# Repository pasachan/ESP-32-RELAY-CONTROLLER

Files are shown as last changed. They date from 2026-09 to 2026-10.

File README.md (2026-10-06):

# ESP32 Relay Controller

**An 8-channel relay controller with Wi-Fi, an RS-485 field bus, and a 12 V power rail for downstream nodes.**
Designed as the master board for a small home-automation network: this board switches loads directly, talks to
the outside world over Wi-Fi, and powers and polls a chain of low-cost slave boards (ATtiny / STM32 class) over RS-485.

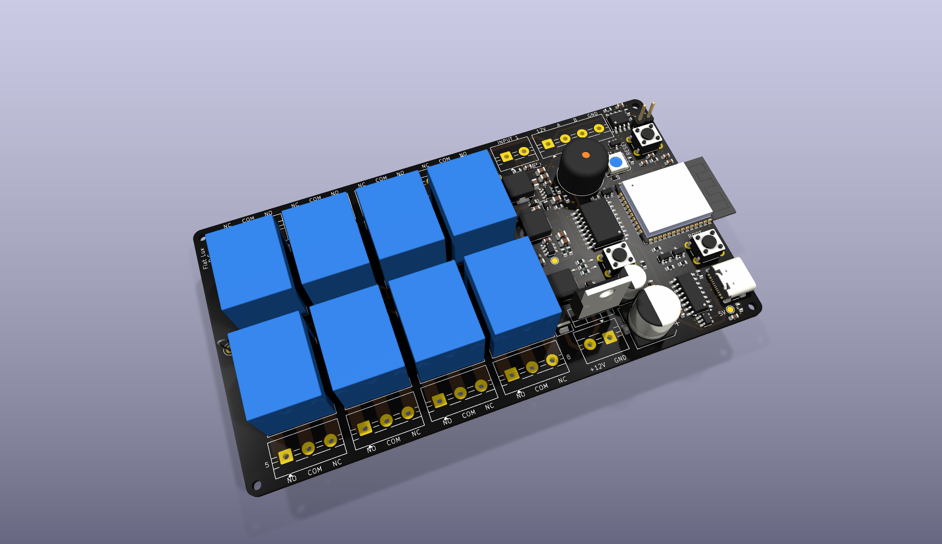
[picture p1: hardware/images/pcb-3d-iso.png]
Board render


Open hardware. KiCad 10 source, fabrication outputs, BOMs with LCSC part numbers, and a pick-and-place file are all in this repository. Rev 1 has been manufactured.

---

## Features

- **ESP32-WROOM-32D** (16 MB flash) — Wi-Fi + Bluetooth, USB-C programming via CH340C with auto-reset
- **8 × SPDT relays** (SRD-05VDC, 10 A contacts), driven by a ULN2803A with built-in flyback clamps, each brought out to a 3-way screw terminal (NO / COM / NC)
- **RS-485 half-duplex master** — MAX3485 (3.3 V), SM712 surge protection, jumper-selectable 120 Ω termination, fail-safe biasing
- **12 V field bus power** on the RS-485 connector, so slave nodes need no local supply
- **12 V input** with P-FET reverse-polarity protection, bidirectional TVS, and an LC input filter
- Two synchronous bucks (LMR51430): 5 V for relay coils, 3.3 V for logic — the 3.3 V rail also runs from USB alone for bench programming
- One dry-contact input (pull-up, RC filter, ESD clamp), active buzzer, WS2812B status LED, rail indicator LEDs
- RESET / BOOT / user (WPS) buttons, 2 mm mounting holes, 124.75 × 68 mm, 2-layer

---

## Block diagram

```mermaid
flowchart LR
    J1["12 V input"] --> Q1["IRF4905<br/>reverse-polarity FET"] --> L3["LC input filter"] --> V12["+12 V rail"]
    D2["SMBJ18CA TVS"] -.clamps.-> J1
    V12 --> U2["LMR51430<br/>buck → 5 V"] --> V5["+5 V coil rail"]
    V12 --> D3["Schottky OR"] --> U3["LMR51430<br/>buck → 3.3 V"] --> V33["+3.3 V logic"]
    USB["USB-C"] --> U4["USBLC6 ESD"] --> U6["CH340C"] <-->|"UART0 + auto-reset"| U1
    USB -->|"VBUS"| D4["Schottky OR"] --> U3
    V33 --> U1["ESP32-WROOM-32D"]
    U1 -->|"8 × GPIO"| U7["ULN2803A"] -->|"8 × coil"| K["K2 … K9<br/>SRD-05VDC SPDT"] --> JT["8 × NO/COM/NC<br/>screw terminals"]
    V5 --> K
    U1 <-->|"UART2 + DE/RE"| U9["MAX3485<br/>RS-485"] --> D6["SM712 TVS"] --> J12["Field bus<br/>12V · A · B · GND"]
    V12 --> J12
    U1 --> BZ["Buzzer"]
    U1 --> LED["WS2812B"]
    IN["Dry-contact input"] --> U1
```

---

## Specifications

| | |
|---|---|
| Supply | 12 V DC nominal (LMR51430 bucks accept 4–36 V; TVS clamps at 18 V standoff) |
| Board draw @ 12 V | ~170 mA idle · ~520 mA worst case (all relays + Wi-Fi TX) |
| Field-bus power budget | ~1.8 A at 12 V on J12 — set by the 1.0 mm feed trace (2.4 A @ 10 °C rise) less the board's own draw; L3 is rated 4.5 A |
| Relay contacts | SPDT, 10 A / 250 VAC rated · **PCB traces sized for ≤ 2.3 A at 12–30 V** (see [design notes](docs/design-notes.md#relay-bank-and-switched-load-clearances)) |
| Relay coil drive | ~4.0 V at the coil vs 3.75 V pick-up spec — all eight channels |
| RS-485 | Half-duplex, 3.3 V transceiver, 120 Ω termination via JP1, 330 Ω fail-safe bias (this node only) |
| USB | USB 2.0 Full Speed (CH340C), USB-C receptacle, 5.1 k CC pull-downs, VBUS ESD array |
| Logic level | 3.3 V throughout; WS2812B fed through a series diode so 3.3 V data meets its V<sub>IH</sub> |
| Dimensions | 124.75 × 68 mm, 1.6 mm FR-4, 2 layers, 1 oz copper |
| Mounting | 4 × Ø2.0 mm holes at the corners |

---

## Repository layout

```
esp32-relay-controller/
├── README.md
├── hardware/
│   ├── kicad/                     KiCad 10 project (schematic, PCB, custom rules, project symbol lib)
│   ├── fabrication/
│   │   ├── gerbers/               RS-274X gerbers + Excellon drill files (fab layers only)
│   │   ├── esp32-relay-controller-gerbers.zip
│   │   ├── BOM.csv                Master BOM — every fitted part, SMD and through-hole, with LCSC + MPN
│   │   ├── BOM-JLCPCB.csv         SMD-only, JLCPCB column format
│   │   ├── BOM-PCBWay.csv         SMD-only, MPN-first for PCBWay
│   │   ├── CPL.csv                SMD pick-and-place (Designator / Mid X / Mid Y / Layer / Rotation)
│   │   └── README.md              How to order
│   └── images/                    Renders and layer plots
├── docs/
│   ├── schematic.pdf
│   ├── design-notes.md            Design decisions, the review process, and what changed as a result
│   └── pinout.md                  ESP32 GPIO map, relay ↔ terminal ↔ GPIO table, connector pinouts
└── firmware/
    ├── README.md                  Pin definitions and the gotchas that bite firmware authors
    └── self-test/                 Bring-up sketch — exercises every component, no libraries needed
```

---

## Getting boards made

Everything a fab needs is in [`hardware/fabrication/`](hardware/fabrication/). The short version:

1. Upload `esp32-relay-controller-gerbers.zip` for the bare PCB — 2 layer, 1.6 mm, 1 oz, any colour.
2. For SMD assembly, upload `BOM-JLCPCB.csv` + `CPL.csv` (JLCPCB) or `BOM-PCBWay.csv` + `CPL.csv` (PCBWay). 72 SMD parts, 35 lines.
3. Hand-fit the 25 through-hole parts: 8 relays, 11 screw-terminal blocks, the TO-220 FET, buzzer, three tact switches and the termination header. All are common parts; LCSC numbers are in `BOM.csv`.

See [`hardware/fabrication/README.md`](hardware/fabrication/README.md) for gerber-origin caveats, the one DFM query a fab may raise, and which parts are safe to substitute.

---

## Firmware quick reference

[`firmware/self-test/`](firmware/self-test/) is a bring-up sketch that exercises every fitted component and prints a pass/fail report over USB serial. Run it first on a new board. Full map in [`docs/pinout.md`](docs/pinout.md), gotchas in [`firmware/README.md`](firmware/README.md).

| Function | GPIO | Notes |
|---|---|---|
| Relay 1 … 8 (silkscreen order) | 14, 19, 25, 13, 23, 33, 32, 18 | Active-high into ULN2803A |
| RS-485 TX / RX / DE+RE | 17 / 16 / 2 | GPIO2 has a 10 k pull-down → receive mode at boot |
| Dry-contact input | 34 | Input-only pin, external 10 k pull-up, closes to GND |
| User button (WPS) | 35 | Input-only, 10 k pull-down, pressed = high |
| Buzzer | 26 | Via NPN, active-high |
| WS2812B data | 27 | Through 330 Ω |
| UART0 (USB) | 1 / 3 | CH340C with DTR/RTS auto-reset |
| I²C | 21 / 22 | Routed to pads but **no pull-ups fitted** in rev 1 |

---

## Design notes

The interesting engineering is in [`docs/design-notes.md`](docs/design-notes.md). Highlights:

- **Why the field bus carries 12 V and not 3.3 V** — cable drop and the thermal ceiling of a SOT-23-6 buck make 3.3 V distribution a dead end past a couple of nodes; regulating at each slave costs one LDO and removes the constraint.
- **Reverse-polarity protection with a P-FET, and why the TVS sits in front of it** — a unidirectional clamp ahead of the FET would short a reversed supply, so it's a bidirectional part.
- **Relay coil drive margin** — the SRD-05VDC needs 3.75 V to pull in; behind a ULN2803A the coil sees ~4.0 V. A series diode in the original design put one channel *under* the limit and was removed.
- **Driving a 5 V WS2812B from a 3.3 V GPIO** — a diode in the LED's supply drops V<sub>DD</sub> into the window where 3.3 V is a valid high, without a level shifter.
- **A KiCad DRC gotcha** — custom rules that match on auto-generated net names like `Net-(J2-Pin_1)` silently never fire. The rules in this project match on a netclass instead.
- **What the design review caught** — the board went through a full netlist, DRC, ERC and geometric-connectivity audit before ordering; the findings and fixes are documented.

---

## Status

| Revision | Date | Notes |
|---|---|---|
| **Rev 1** | Sep 2026 | Ordered. 0 DRC errors, 0 unconnected nets, all nets verified single-island. |
| **Rev 1** | Oct 2026 | **Built and brought up.** All eight relays, the buzzer, the WS2812B, both inputs, the RS-485 receiver and the USB programming path work. One firmware-level finding: the MAX3485's RO pin is tri-stated during transmit and has no pull-up, so it needs one enabled in software — [details](firmware/self-test/README.md#finding-ro-floats-during-transmit). |

Known rev 1 limitations and the planned rev 2 changes are listed at the end of the [design notes](docs/design-notes.md#rev-2-backlog).

---

## Licence

Copyright © 2026 Pareekshit Sachan.

This source describes Open Hardware and is licensed under the **CERN-OHL-P v2** (`SPDX-License-Identifier: CERN-OHL-P-2.0`). You may redistribute and modify this documentation and make products using it under the terms of the CERN-OHL-P v2 — see [`LICENSE`](LICENSE) or <https://cern.ch/cern-ohl>.

This documentation is distributed WITHOUT ANY EXPRESS OR IMPLIED WARRANTY, INCLUDING OF MERCHANTABILITY, SATISFACTORY QUALITY AND FITNESS FOR A PARTICULAR PURPOSE. Please see the CERN-OHL-P v2 for applicable conditions.

Symbols, footprints and 3D models from the KiCad libraries are used under the [KiCad library licence](https://www.kicad.org/libraries/license/) (CC-BY-SA 4.0 with exception). Datasheets referenced in the design notes remain the property of their manufacturers.

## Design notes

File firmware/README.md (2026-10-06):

# Firmware

[`self-test/`](self-test/) is a hardware bring-up sketch that exercises every fitted component and prints a pass/fail report over USB serial. It needs no libraries beyond the Arduino-ESP32 core. Run it first on a new board — it validates the relay silkscreen-to-GPIO mapping, which is not in an obvious order.

No application firmware is included yet. The rest of this file carries the hardware facts a firmware author needs on day one; the full table is in [`docs/pinout.md`](../docs/pinout.md).

## Pin definitions

```c
// Relays, in silkscreen order 1–8. Active-high into a ULN2803A.
static const uint8_t RELAY_GPIO[8] = { 14, 19, 25, 13, 23, 33, 32, 18 };

// RS-485 (MAX3485, half duplex) on UART2
#define RS485_TX_GPIO     17
#define RS485_RX_GPIO     16
#define RS485_DIR_GPIO     2   // high = transmit. External 10k pull-down → receive at boot.
                               // After Serial2.begin(), pull RS485_RX_GPIO up — see below.

// Inputs
#define INPUT1_GPIO       34   // dry contact to GND, external 10k pull-up, closed = LOW. Input-only pin.
#define USER_BUTTON_GPIO  35   // pressed = HIGH, external 10k pull-down. Input-only pin.

// Indicators
#define BUZZER_GPIO       26   // high = on
#define STATUS_LED_GPIO   27   // WS2812B data, single pixel

// I2C — routed to GPIO21/22 but no pull-ups fitted in rev 1
#define I2C_SDA_GPIO      21
#define I2C_SCL_GPIO      22
```

## Things worth knowing

- **Relays are off through reset and boot.** The ULN2803A inputs read low while the ESP32 pins are high-impedance. Initialise the relay GPIOs low before setting them as outputs to avoid a glitch.
- **GPIO2 (RS-485 direction) is a boot-strapping pin.** The external pull-down keeps it low at boot, which is what the ESP32 needs and also parks the transceiver in receive mode. Don't add an internal pull-up.
- **GPIO34 and GPIO35 are input-only** and have no internal pull resistors; the board provides external ones.
- **Turn-around on the RS-485 bus:** raise `RS485_DIR_GPIO` before writing, wait for the UART TX FIFO to drain (`uart_wait_tx_done`, or `Serial2.flush()` under Arduino), then drop it. Dropping it early truncates the last byte.
- **Pull the RS-485 RX pin up in software.** DE and RE̅ are tied together, so enabling the driver also disables the receiver — and a disabled MAX3485 drives RO to high impedance. Rev 1 fits no pull-up on RO, so GPIO16 floats for the whole of every transmission and the UART clocks in phantom bytes off the adjacent DI line. Measured on the first board: ~5 junk bytes per 18-byte frame at 9600 baud, with nothing attached to the bus. One line fixes it:

  ```c
  Serial2.begin(9600, SERIAL_8N1, RS485_RX_GPIO, RS485_TX_GPIO);
  gpio_set_pull_mode((gpio_num_t)RS485_RX_GPIO, GPIO_PULLUP_ONLY);  // must follow begin()
  ```

  That took the count to zero. A 10 kΩ pull-up on RO is in the rev 2 backlog.
- **The 5 V rail is absent on USB-only power**, so relays, the buzzer and the WS2812B do nothing while you're programming from a laptop. The 3.3 V logic rail works normally.
- **Module is the 16 MB flash variant** (ESP32-WROOM-32D-N16). Pick a matching partition table — `default_16MB.csv` under PlatformIO, or "16M Flash (3MB APP/9.9MB FATFS)" in the Arduino IDE.
- **Pick an upload rate that divides 6 MHz exactly** — 1500000, 1000000, 750000, 460800. **921600 and 576000 fail**, and not because they are too fast: 1500000 works and is 1.6× quicker. The CH340C's reachable rates are 6 000 000 / n on this host, so 921600 lands on 857143 instead, 7 % low, and the UART misframes. Details and the measured table are in [`self-test/README.md`](self-test/README.md#finding-the-ch340c-cannot-express-921600).

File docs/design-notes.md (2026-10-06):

# Design notes

Decisions, the reasoning behind them, and what a pre-fabrication review changed. Numbers quoted are measured from the KiCad files or taken from the referenced datasheets, not estimated.

Contents

- [Power input and protection](#power-input-and-protection)
- [Regulators](#regulators)
- [Relay bank and switched-load clearances](#relay-bank-and-switched-load-clearances)
- [Relay coil drive margin](#relay-coil-drive-margin)
- [RS-485 field bus](#rs-485-field-bus)
- [Why the bus carries 12 V, not 3.3 V](#why-the-bus-carries-12-v-not-33-v)
- [USB](#usb)
- [Status LED level shifting](#status-led-level-shifting)
- [Indicator LEDs](#indicator-leds)
- [Layout notes](#layout-notes)
- [Design-rule gotcha: net names with parentheses](#design-rule-gotcha-net-names-with-parentheses)
- [What the pre-order review caught](#what-the-pre-order-review-caught)
- [Rev 2 backlog](#rev-2-backlog)

---

## Power input and protection

```
J1 (+12 V) ──► D2 SMBJ18CA ──► Q1 IRF4905 ──► L3 10 µH ──► +12V_Protected ──► bucks, field bus
                (to GND)        P-FET             ▲
                                                  C1 470 µF · C2 100 µF · C12 10 µF
```

**Reverse-polarity protection is a P-channel MOSFET, not a diode.** Q1 (IRF4905, 20 mΩ) is wired drain-to-input, source-to-load, gate pulled to ground through 100 k with a 16 V zener (D5, BZX84-C16) clamping V<sub>GS</sub>. At the board's ~600 mA draw that is 12 mV of drop and 7 mW of loss; a Schottky in the same position would drop ~400 mV and burn 240 mW. With the input reversed the body diode is reverse-biased and V<sub>GS</sub> is zero, so nothing conducts.

The gate zener's orientation was worth checking against the part rather than the symbol: the BZX84 in SOT-23 is pin 1 = anode, pin 2 = no connection, pin 3 = cathode. The schematic uses KiCad's `Diode:BZX84Cxx` symbol, which has that pinout; a generic two-pin zener symbol on a three-pad footprint would put the anode on the NC pin and silently remove the clamp on the next schematic-to-PCB sync.

**The TVS sits ahead of the FET, and is bidirectional.** An earlier revision had a unidirectional SMAJ18A *after* the input inductor. A surge on the input then reached Q1's drain (rated −55 V) before anything clamped it, and L3's V = L·di/dt during the edge added tens of volts on top of the clamp voltage. Moving the clamp to the connector fixes that — but a *unidirectional* TVS ahead of the reverse-polarity FET would forward-conduct on a reversed supply and short it, defeating Q1. Hence SMBJ18**CA**: 18 V standoff both ways, 600 W.

**L3 is an EMI filter, not surge protection.** Two synchronous bucks switching at ~1.1 MHz draw pulsed current from the +12 V node. L3's impedance at that frequency is ~69 Ω against C12's ~0.05 Ω, giving roughly 63 dB of attenuation before the ripple reaches the supply wiring. The original 22 µH part in a 4.4 × 4.2 mm package was rated ~1.5 A and became the limiting element once the board started supplying a field bus; it was replaced with a 10 µH / 4.5 A part (FXL0630-100-M) on the same footprint already used for L1 and L2. The 7 dB of filtering given up is immaterial; the LC resonance moves from ~1.4 kHz to ~2.1 kHz, which is if anything better for stability against the bucks' constant-power input characteristic.

## Regulators

Two LMR51430 (4–36 V in, 3 A, SOT-23-6):

| | V<sub>out</sub> | Divider | Feeds |
|---|---|---|---|
| U2 | 0.6 × (1 + 100k / 13.7k) = **4.98 V** | R1 / R2 | Relay coils, buzzer, WS2812B |
| U3 | 0.6 × (1 + 100k / 22.1k) = **3.32 V** | R3 / R4 | ESP32, CH340C, MAX3485 |

EN is tied to VIN on both, which the LMR51430 datasheet gives as the recommended self-start configuration.

U3's input is diode-ORed from +12 V (D3) and USB VBUS (D4), so the logic rail runs from USB alone for programming on the bench. The 5 V rail does not — relays are deliberately inert on USB power. USB minus one Schottky drop is ~4.65 V, above the LMR51430's 4 V minimum, and the ~71 % duty cycle is well inside the part's range.

Switch-node copper is 5–6 mm² per buck, single-layer, no vias; the feedback traces have zero parallel run within 1.5 mm of either switch node. Input ceramics are 0.7 mm and 1.0 mm from the VIN pins.

## Relay bank and switched-load clearances

Eight SRD-05VDC-SL-C relays (Form C, 10 A / 250 VAC contacts) driven by a ULN2803A. COM pin 10 of the ULN is tied to the 5 V coil rail so the internal clamp diodes provide the flyback path.

**This revision is laid out for low-voltage loads.** The contact traces are 1.0 mm on 1 oz copper — about 2.3 A at 10 °C rise, 3.1 A at 20 °C. On the bottom layer the eight coil-drive traces run through the relay contact-pin field at **0.2 mm** from the contact pads, and the ground pour comes to **0.5 mm** of them. Both are fine for 12–30 V (IPC-2221 external needs 0.1 mm) and would be unacceptable for mains: 230 V needs ≥ 1.25 mm even functionally, and a safety barrier under IEC 62368 wants 3 mm+ of creepage with a routed slot between the switched side and the controller. Adapting this board for mains is a relay-bank re-layout, not a rule change.

The silkscreen NO / NC labelling was verified against the SANYOU SRD datasheet rather than the generic KiCad symbol. The datasheet's Form 1c wiring diagram (bottom view) places the resting contact on what becomes KiCad pad 4 after mirroring to top view — so pad 4 is NC and pad 3 is NO. All 24 labels match.

## Relay coil drive margin

SRD-05VDC: 70 Ω coil, 71.4 mA, must-operate at 75 % of nominal = **3.75 V**.

```
5 V rail (nominal)                4.98 V
ULN2803A V_CE(sat) @ 71 mA       −0.90 V  (typ; 1.1 V max)
                                 ────────
Coil voltage                      4.08 V   (3.88 V at max V_CE(sat))
```

An earlier revision fed one relay through a series Schottky to allow it to operate on USB power. That channel's coil then sat at 3.73 V — under the pick-up spec at typical values and near 3.3 V worst case. The diode was removed; all eight channels now share the same 0.3 V of margin. If more headroom is ever wanted, R2 = 13.0 k lifts the rail to 5.22 V.

Total ULN2803A dissipation with all eight coils energised is ~0.5 W in SOIC-18W — within its rating, warm to the touch.

## RS-485 field bus

MAX3485 (3.3 V, half-duplex), with RE̅ and DE tied together on GPIO2.

**GPIO2 is a strapping pin, and that is used deliberately.** R22 (10 k) pulls it to ground, so during reset and boot the transceiver is in receive-only mode and cannot drive the bus while the MCU is undefined. The pull-down also satisfies the ESP32's boot-strapping requirement for that pin.

**Termination** is 120 Ω (R23) in series with a jumper (JP1) across A/B — fitted only at the two physical ends of the bus.

**Fail-safe bias** is 330 Ω from 3.3 V to A (R26) and 330 Ω from B to ground (R27). With one 120 Ω terminator that holds the idle differential at ~508 mV; with terminators at both ends, ~275 mV — both above the 200 mV receiver threshold. The 330 Ω pair is on the heavy side: with two terminators the DC load works out to ~55 Ω against RS-485's 54 Ω minimum, so **only this node should bias**. If another node also needs to, 560 Ω–1 k here would give headroom.

**Protection** is an SM712 (D6), the asymmetric 7 V / 12 V array made for RS-485's −7 to +12 V common-mode range. The datasheet specifies it as "Pin 3-1 and Pin 3-2", confirming pin 3 as common; KiCad's `Diode:SM712_SOT23` symbol matches.

The connector is 12 V · A · B · GND. Silkscreen matches the netlist.

**RO goes high-impedance during transmit, and rev 1 has no pull-up on it.** Found during bring-up, not design review. Because RE̅ and DE are tied together, enabling the driver also disables the receiver, and a disabled MAX3485 tri-states RO. With no pull-up fitted, GPIO16 floats for the whole of every transmission — ~19 ms for an 18-byte frame at 9600 baud — and the ESP32's UART clocks in phantom bytes from crosstalk off the adjacent DI line. The first board produced about five junk bytes per frame **with nothing attached to J12 and JP1 open**, so they could only be self-generated.

Two things it was not: lengthening the mark hold before dropping DE changed nothing (26 bytes before, 26 after), which rules out a truncated turn-around, and the fail-safe bias is solid — the receiver reads a clean idle high on 20 of 20 samples when the driver is off. Enabling the ESP32's internal pull-up on GPIO16 after `Serial2.begin()` took the count to zero.

So rev 1 is fully usable with one line of firmware, and rev 2 should fit a 10 kΩ pull-up from RO to 3.3 V, which is what most RS-485 reference designs include for exactly this reason.

## Why the bus carries 12 V, not 3.3 V

The first idea was to put 3.3 V on the field connector so slave boards need no regulator. Three things kill that.

**Cable drop.** 24 AWG is 0.168 Ω/m round-trip. Eight nodes at 30 mA each over a 30 m run:

```
distributing 3.3 V:  240 mA × 30 m × 0.168 = 1.2 V drop  →  node sees 2.1 V   (dead)
distributing 12 V:   240 mA × 30 m × 0.168 = 1.2 V drop  →  node sees 10.8 V  (fine)
```

Same absolute drop; on 3.3 V it kills the remote transceiver, on 12 V the local regulator never notices.

**The 3.3 V buck's thermal ceiling.** U3 is a SOT-23-6 at ~82 % efficiency from 12 V. One amp out is ~0.7 W of loss — roughly 90 °C of rise — so it can realistically supply the board's own ~600 mA peak plus perhaps 200–300 mA more. Not a bus.

**Fault isolation.** A short on a 3.3 V field pin collapses the same rail the ESP32 runs on. On the 12 V rail there is 570 µF of bulk and the input protection between the fault and the controller.

So each slave regulates locally. At 30 mA a 12 → 3.3 V LDO burns 0.26 W (use SOT-89 or a small buck); the feed pin has ~1.8 A available, and RS-485's 32-unit-load limit will be reached long before the current budget is.

Rev 1 has no current limiting on the 12 V feed pin — see the [rev 2 backlog](#rev-2-backlog).

## USB

USB 2.0 Full Speed (12 Mbps). At that speed a 4 ns edge is ~60 cm long in FR-4 and impedance control is irrelevant for anything under ~10 cm. D+ is 24.6 mm, D− 22.7 mm (two vias), skew 1.8 mm ≈ 12 ps. The pair is 35 mm from the nearest switch node and 24 mm from the nearest relay coil trace. The only tracks crossing under it on the back layer are the UART0 lines.

5.1 k pull-downs on CC1 and CC2 (correct sink configuration), USBLC6-2SC6 ESD array on D+/D−/VBUS, 4.7 µF on VBUS. The CH340C runs at 3.3 V with V3 tied to VCC; the standard two-transistor DTR/RTS auto-reset circuit drives EN and GPIO0.

## Status LED level shifting

A WS2812B needs V<sub>DD</sub> between 3.5 and 5.3 V and defines V<sub>IH</sub> as 0.7 × V<sub>DD</sub>. From a 5 V supply that is 3.5 V — above what a 3.3 V GPIO can drive — and running the LED from 3.3 V is below its minimum supply. The window that satisfies both is 3.5–4.71 V.

The fix is a 1N4148 in series with the LED's supply (D1) with the 100 nF bypass (C17) on the LED side of it:

```
                  V_f      V_DD at LED    V_IH = 0.7·V_DD    3.3 V drive
low brightness   0.65 V      4.35 V          3.05 V             ✓
full white       0.90 V      4.10 V          2.87 V             ✓
```

One diode instead of a level shifter, with 250–400 mV of margin.

## Indicator LEDs

Three 0201 red LEDs (V<sub>f</sub> ≈ 1.9 V) on the 3.3 V, 5 V and 12 V rails. The 3.3 V one is the constraint: an early pick was a white 0201 at V<sub>f</sub> 2.6–3.2 V, which on a 3.3 V rail through 1 k gives 0.4 mA at typical V<sub>f</sub> and 0.1 mA at the top of the spread — invisible, and dominated by part-to-part variation rather than the resistor. Red through 330 Ω gives 4.2 mA and doesn't care about V<sub>f</sub> spread.

## Layout notes

- 2-layer, solid ground pour on the bottom, 30 stitching vias plus 24 through-hole ground pads.
- ESP32 antenna section overhangs the board edge by 6.5 mm; all castellated pads are on copper and the module's keep-out is entirely off-board.
- The last ~9 mm of 3.3 V into the ESP32 is 0.2 mm trace (22 mΩ, 11 mV at a 500 mA Wi-Fi burst); C21 (10 µF) sits 3 mm from the pin and C14 (100 nF) 1 mm.
- The USB-C receptacle sits 0.58 mm behind the board edge — inside KiCad's edge marker for that footprint. Some cables seat fully, some don't; a light file on the edge fixes it on a built board.
- Netclass clearance is 0.15 mm; hole-to-copper is 0.18 mm to accommodate the GCT USB-C footprint's own 0.194 mm NPTH spacing. Both inside standard 2-layer capability at JLCPCB and PCBWay.

## Design-rule gotcha: net names with parentheses

The project's custom DRC rules for the relay bank originally read:

```
(rule "Relay contact clearance 1mm"
  (condition "A.NetName == 'Net-(J10-Pin_1)' || A.NetName == 'Net-(J2-Pin_2)' || ...")
  (constraint clearance (min 1.0mm)))
```

They never fired. A canary rule on `'GND'` produced 507 violations, a rule on `'Relay1'` produced 28, but any condition matching a name of the form `Net-(Jx-Pin_y)` produced zero — KiCad 10's rule parser does not match net names containing parentheses, and it does not warn. The board passed DRC with 0.2 mm clearances against a rule demanding 1.0 mm.

The fix in this repository: the project file assigns those nets to a `RelayContacts` netclass by the pattern `Net-(J*-Pin_*)`, and the rules match on `A.NetClass == 'RelayContacts'`. Verified by a 5 mm probe rule against the class (244 hits) before setting the real limits.

The limits now in `esp32-relay-controller.kicad_dru` are what a low-voltage board should meet, and this board does: ≥ 1.0 mm between different switched-load nets, ≥ 0.5 mm to the ground pour, ≥ 0.2 mm to everything else.

## What the pre-order review caught

Before ordering, the design went through KiCad DRC and ERC, a schematic-parity check, and an independent geometric connectivity and clearance pass over every pad, track, via and zone polygon. Things it found and that were fixed, roughly in order of severity:

1. **Eight broken nets in an intermediate layout** — the 5 V buck's ground pin, the CH340C's 3.3 V feed and the I²C pull-ups were each on isolated copper islands. KiCad's DRC reported them as unconnected items; the geometric pass found the same eight independently.
2. **A stale zone fill** that overlapped USB D− with the ground pour. `kicad-cli pcb export gerbers` does not refill zones by default; plotted as-is that board would have shipped with USB shorted.
3. **A 2-pin zener symbol on a 3-pad SOT-23 footprint.** The copper was right; the schematic was wrong, and a schematic-to-PCB sync would have moved the anode net onto the package's NC pin.
4. **Two input terminals swapped between schematic and layout**, and a series Schottky that put one relay coil below its pick-up voltage.
5. **A 0.035 mm clearance** between +12 V and ground after a rework of the input filter.
6. **An inductor whose BOM part didn't fit its footprint** — pad pitch differed by 0.7 mm between the part ordered and the land pattern on the board.
7. **Part-number fields that lagged value changes** — after a resistor was changed from 1 k to 330 R and an inductor from 22 µH to 10 µH, the LCSC / MPN fields still pointed at the old parts. Worth a final field-consistency check on any BOM exported from a schematic that has been edited.
8. **A field bus connector with 3.3 V on it** — see [above](#why-the-bus-carries-12-v-not-33-v).

Two things it checked and left alone, which is also worth recording: the NO / NC silkscreen (a first pass using the generic relay symbol's drawn contact suggested all 16 were swapped; the SRD datasheet showed the silkscreen was right), and the SHT4x pinout (pin 2 really is SCL — the datasheet confirms it, against a common expectation that it is ground).

## Rev 2 backlog

Nothing here affects rev 1 functioning as designed for low-voltage loads.

- **Current-limit the 12 V field-bus pin.** A 500 mA–750 mA PPTC in series with J12 pin 1 prevents a shorted cable becoming a sustained fault; a dedicated small buck for the bus would additionally keep the controller from browning out during one. Add an 18 V TVS at the connector while there — the input TVS is upstream of the filter and does not protect this node.
- **Reorder the field connector to A · B · GND · 12 V** so ground separates the bus pair from the power pin; a one-position wiring slip currently puts 12 V on the RS-485 line and through the SM712.
- **Move the coil-drive traces out of the relay contact field**, widen contact traces to 2.5–3 mm or go to 2 oz, and add a slot under the relay bank — the pre-requisites for any mains variant.
- **Fit a 10 kΩ pull-up from MAX3485 RO to 3.3 V.** RO is tri-stated whenever the driver is enabled, so GPIO16 floats during every transmission and the UART receives phantom bytes. Worked around in firmware today; see [above](#rs-485-field-bus).
- **Add I²C pull-ups (or a header)** — GPIO21/22 are routed but unpopulated after the on-board humidity sensor was dropped for space.
- **Widen 3.3 V distribution to 0.5 mm**, route D+/D− together on one layer, and put the USB ESD array in-line rather than on a detour.
- **Silkscreen numbers on all eight relays** (only the four corners are labelled), and clear the remaining silk-over-pad overlaps.
- **Nudge the USB-C receptacle 0.58 mm outward** so its mating face is flush with the board edge.
- A few more ground stitching vias along the buck area and around the ESP32.

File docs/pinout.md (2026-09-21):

# Pinout

Everything below is extracted from the rev 1 netlist. GPIO numbers are ESP32 GPIO numbers (not module pad numbers).

## ESP32 GPIO map

| GPIO | Net | Direction | Function | Notes |
|---|---|---|---|---|
| 0 | IO0 | in | BOOT | 10 k pull-up, BOOT button to GND, auto-reset transistor |
| 1 | TX | out | UART0 TXD | → CH340C RXD |
| 2 | Direction | out | RS-485 DE + RE̅ | **Strapping pin.** 10 k pull-down (R22) → receive mode at boot. Drive high to transmit. |
| 3 | RX | in | UART0 RXD | ← CH340C TXD |
| 13 | R1_GPIO | out | Relay coil (K9) | ULN2803A IN1 |
| 14 | R2_GPIO | out | Relay coil (K2) | ULN2803A IN2 |
| 16 | RX1 | in | UART2 RXD | ← MAX3485 RO |
| 17 | TX1 | out | UART2 TXD | → MAX3485 DI |
| 18 | R5_GPIO | out | Relay coil (K7) | ULN2803A IN5 |
| 19 | R6_GPIO | out | Relay coil (K5) | ULN2803A IN6 |
| 21 | SDA | — | I²C SDA | Routed, **no pull-up fitted** in rev 1 |
| 22 | SCL | — | I²C SCL | Routed, **no pull-up fitted** in rev 1 |
| 23 | R7_GPIO | out | Relay coil (K3) | ULN2803A IN7 |
| 25 | R8_GPIO | out | Relay coil (K4) | ULN2803A IN8 |
| 26 | BUZZER | out | Active buzzer | Via SS8050 NPN, 4.7 k base resistor. High = on. |
| 27 | Status_led | out | WS2812B DIN | Through 330 Ω. LED V<sub>DD</sub> is ~4.3 V (5 V via series diode). |
| 32 | R3_GPIO | out | Relay coil (K6) | ULN2803A IN3 |
| 33 | R4_GPIO | out | Relay coil (K8) | ULN2803A IN4 |
| 34 | Switch_1 | in | INPUT 1 (dry contact) | **Input-only.** 10 k pull-up to 3.3 V, 100 nF to GND, PESD3V3 clamp. Closed = low. |
| 35 | — | in | WPS / user button | **Input-only.** 10 k pull-down, button to 3.3 V. Pressed = high. |
| EN | EN | in | Reset | 10 k pull-up, 1 µF, RESET button, auto-reset transistor |

Unused and left unconnected: GPIO 4, 5, 12, 15, 36, 39 and the flash SD pins. GPIO 12 (MTDI) and GPIO 15 are unconnected so their boot-strap defaults apply.

Relay outputs are **active-high** — a high on the GPIO turns the ULN2803A channel on and energises the coil. All eight GPIOs are ordinary outputs with no boot-time side effects; the ULN inputs read low while the ESP32 is in reset, so relays stay off through boot.

## Relay ↔ terminal ↔ GPIO

Relays are numbered on the silkscreen 1–4 across the top row (left to right, viewed with the power input at the bottom right) and 5–8 across the bottom. Only the four corners carry a printed number in rev 1; the rest follow by position.

| Silk # | Terminal | Relay | ULN2803A | GPIO |
|---|---|---|---|---|
| 1 | J3 | K2 | IN2 → OUT2 | **14** |
| 2 | J9 | K5 | IN6 → OUT6 | **19** |
| 3 | J11 | K4 | IN8 → OUT8 | **25** |
| 4 | J2 | K9 | IN1 → OUT1 | **13** |
| 5 | J10 | K3 | IN7 → OUT7 | **23** |
| 6 | J6 | K8 | IN4 → OUT4 | **33** |
| 7 | J4 | K6 | IN3 → OUT3 | **32** |
| 8 | J8 | K7 | IN5 → OUT5 | **18** |

Array form, in silkscreen order:

```c
static const uint8_t RELAY_GPIO[8] = { 14, 19, 25, 13, 23, 33, 32, 18 };
```

Each terminal is **NO · COM · NC** as printed. The labelling was verified against the SANYOU SRD datasheet (Form 1c, bottom view mirrored to top): KiCad pad 1 = COM, pad 3 = NO, pad 4 = NC.

## Connectors

### J1 — power input (2-way, 5.00 mm)

| Pin | Silk | Net |
|---|---|---|
| 1 | GND | GND |
| 2 | +12V | Input, ahead of reverse-polarity FET and TVS |

12 V nominal. The downstream regulators accept 4–36 V; the input TVS stands off 18 V. Reverse connection is blocked, not clamped.

### J12 — RS-485 field bus (4-way, 5.00 mm)

| Pin | Silk | Net | Notes |
|---|---|---|---|
| 1 | 12V | +12V_Protected | Bus power for slave nodes. **No current limit in rev 1.** ~1.8 A available. |
| 2 | A | RS-485 A | Non-inverting. 330 Ω to 3.3 V fail-safe bias. |
| 3 | B | RS-485 B | Inverting. 330 Ω to GND fail-safe bias. |
| 4 | GND | GND | Bus reference |

Daisy-chain A/B/GND through each node; terminate with 120 Ω only at the two physical ends. This board's terminator is enabled by fitting a jumper on **JP1**. Bias at this node only.

### J7 — INPUT 1 (2-way, 5.00 mm)

| Pin | Net | Notes |
|---|---|---|
| 1 | Switch_1 | → GPIO34 via 10 k pull-up |
| 2 | GND | |

Dry contact (switch, reed, relay) between the two pins. No series resistance ahead of the GPIO — keep it to short, in-enclosure runs, or add ~1 k in series for field wiring.

### J5 — USB-C

USB 2.0 device. Powers the 3.3 V logic rail (not the relays) when 12 V is absent. Programming via the CH340C at up to the usual ESP32 rates; auto-reset via DTR/RTS.

### JP1 — RS-485 termination

2-pin 2.54 mm header. Jumper fitted = 120 Ω across A/B.

## Buttons

| Ref | Silk | Function |
|---|---|---|
| SW1 | RESET | Pulls EN low |
| SW2 | BOOT | Pulls GPIO0 low (hold during reset for download mode) |
| SW3 | WPS | User button on GPIO35, active-high |

## Test points

| Ref | Net |
|---|---|
| TP1 | +12V_Protected |
| TP2 | +5 V (relay rail) |
| TP3 | +3.3 V |
| TP4 | GND (wire loop) |
| TP10 | USB VBUS |

## LEDs

| Ref | Rail | Colour |
|---|---|---|
| D7 | 3.3 V | red |
| D9 | 5 V | red |
| D11 | 12 V | red |
| D15 | WS2812B status LED | RGB, GPIO27 |

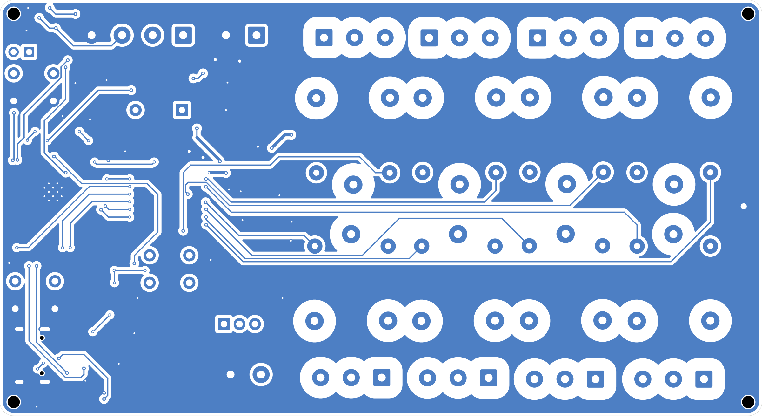
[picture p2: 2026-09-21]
hardware/images/pcb-bottom.png

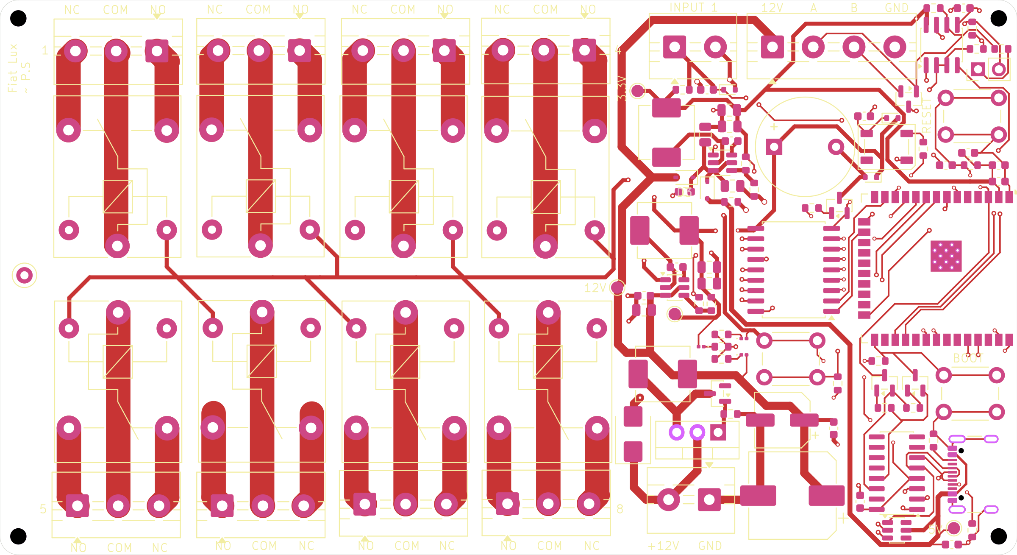
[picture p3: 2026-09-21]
hardware/images/pcb-top.png

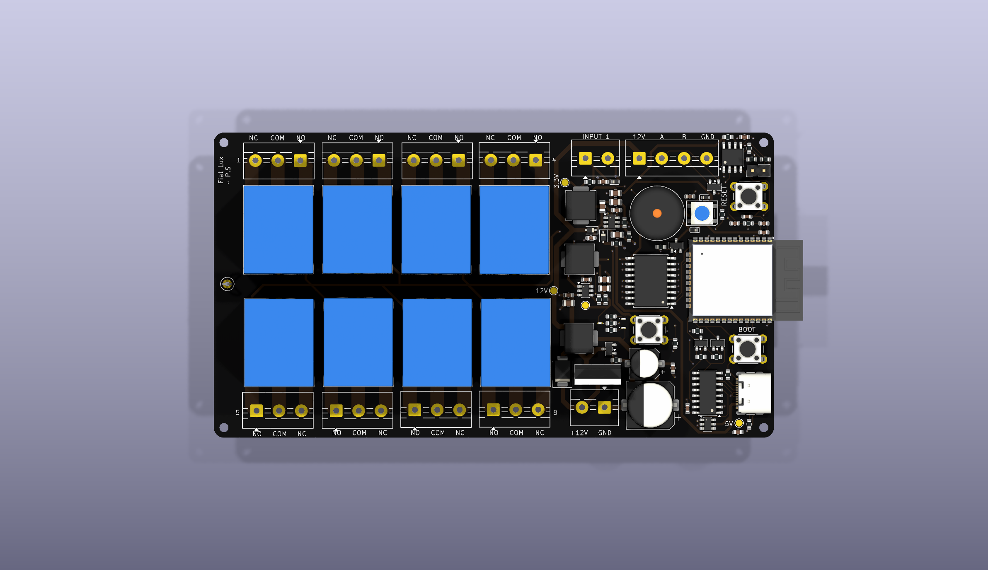
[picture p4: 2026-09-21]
hardware/images/pcb-3d-top.png

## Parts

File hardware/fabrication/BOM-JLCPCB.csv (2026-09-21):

Comment | Designator | Footprint | LCSC Part #
470uF 35V elec 105C | C1 | CP_Elec_10x10.5 | C976030
100uF 35V elec | C2 | CP_Elec_6.3x7.7 | C19270708
100nF 50V X7R | C3,C4,C5,C6,C9,C14,C17,C18,C23,C25 | C_0603_1608Metric | C1591
22uF 16V X5R | C7,C8,C10,C11 | C_0805_2012Metric | C296720
10uF 50V X5R | C12,C13,C15 | C_0805_2012Metric | C440198
1uF 50V X5R | C19,C20 | C_0603_1608Metric | C15849
10uF 25V X5R | C21,C22 | C_0603_1608Metric | C96446
1N4148WT-7 switching diode | D1,D13 | D_SOD-523 | C83482
SMBJ18CA TVS 18V bidirectional | D2 | D_SMB | C2938922
CUS10S30 Schottky 30V 1A | D3,D4 | D_SOD-323 | C27636107
BZX84-C16 zener 16V | D5 | SOT-23 | C550938
CDSOT23-SM712 RS-485 TVS | D6 | SOT-23 | C404012
LED red 0201 | D7,D9,D11 | LED_0201_0603Metric | C52675906
PESD3V3S1UB ESD 3.3V | D8 | D_SOD-523 | C2912529
WS2812B-B/T RGB LED | D15 | LED_WS2812B_PLCC4_5.0x5.0mm_P3.2mm | C2761795
USB-C receptacle 16P | J5 | USB_C_Receptacle_GCT_USB4105-xx-A_16P_TopMnt_Horizontal | C5184243
6.8uH inductor | L1 | L_Changjiang_FXL0630 | C5349706
5.6uH inductor | L2 | L_Changjiang_FXL0630 | C475914
10uH 4.5A molded inductor | L3 | L_Changjiang_FXL0630 | C167223
SS8050 NPN 1.5A | Q2,Q3,Q5 | SOT-23 | C2150
100k 1% | R1,R3,R5 | R_0603_1608Metric | C25803
13.7k 1% | R2 | R_0603_1608Metric | C22793
22.1k 1% | R4 | R_0603_1608Metric | C2960862
5.1k 1% | R6,R7 | R_0603_1608Metric | C23186
10k 1% | R8,R9,R10,R15,R22,R24,R25 | R_0603_1608Metric | C25804
4.7k 1% | R14,R18,R40 | R_0603_1608Metric | C23162
120R 1% | R23 | R_0603_1608Metric | C22787
330R 1% | R26,R27,R37,R42 | R_0603_1608Metric | C23138
1k 1% | R38 | R_0603_1608Metric | C21190
ESP32-WROOM-32D-N16 module | U1 | ESP32-WROOM-32D | C529578
LMR51430 buck 4-36V 3A | U2,U3 | SOT-23-6 | C5185863
USBLC6-2SC6 USB ESD array | U4 | SOT-23-6 | C7519
CH340C USB-UART | U6 | SOIC-16_3.9x9.9mm_P1.27mm | C84681
ULN2803A Darlington driver | U7 | SOIC-18W_7.5x11.6mm_P1.27mm | C845537
MAX3485AEASA+T RS-485 transceiver | U9 | SOIC-8_3.9x4.9mm_P1.27mm | C94609

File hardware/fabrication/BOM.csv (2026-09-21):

Item | Designator | Qty | Description | Manufacturer Part Number | Manufacturer | Footprint | Type | LCSC Part # | Comment
1 | C1 | 1 | 470uF 35V elec 105C | RVT1V471M1010 470UF 35V | DMBJ | CP_Elec_10x10.5 | SMD | C976030
2 | C2 | 1 | 100uF 35V elec | JBLM2101M035C070RTM 100UF 35V | DMBJ | CP_Elec_6.3x7.7 | SMD | C19270708
3 | C3,C4,C5,C6,C9,C14,C17,C18,C23,C25 | 10 | 100nF 50V X7R | CL10B104KB8NNNC | Samsung Electro-Mechanics | C_0603_1608Metric | SMD | C1591
4 | C7,C8,C10,C11 | 4 | 22uF 16V X5R | CL21A226KOQNNNE | Samsung Electro-Mechanics | C_0805_2012Metric | SMD | C296720
5 | C12,C13,C15 | 3 | 10uF 50V X5R | GRM21BR61H106KE43L | Murata | C_0805_2012Metric | SMD | C440198
6 | C19,C20 | 2 | 1uF 50V X5R | CL10A105KB8NNNC | Samsung Electro-Mechanics | C_0603_1608Metric | SMD | C15849
7 | C21,C22 | 2 | 10uF 25V X5R | CL10A106MA8NRNC | Samsung Electro-Mechanics | C_0603_1608Metric | SMD | C96446
8 | D1,D13 | 2 | 1N4148WT-7 switching diode | 1N4148WT-7 | Diodes Incorporated | D_SOD-523 | SMD | C83482
9 | D2 | 1 | SMBJ18CA TVS 18V bidirectional | SMBJ18CA | RUILON | D_SMB | SMD | C2938922
10 | D3,D4 | 2 | CUS10S30 Schottky 30V 1A | CUS10S30 | DOWO | D_SOD-323 | SMD | C27636107
11 | D5 | 1 | BZX84-C16 zener 16V | BZX84-C16,235 | Nexperia | SOT-23 | SMD | C550938
12 | D6 | 1 | CDSOT23-SM712 RS-485 TVS | CDSOT23-SM712 | Bourns | SOT-23 | SMD | C404012
13 | D7,D9,D11 | 3 | LED red 0201 | CT-0201URC-P4 | CHONGTIAN | LED_0201_0603Metric | SMD | C52675906
14 | D8 | 1 | PESD3V3S1UB ESD 3.3V | PESD3V3S1UB | TECH PUBLIC | D_SOD-523 | SMD | C2912529
15 | D15 | 1 | WS2812B-B/T RGB LED | WS2812B-B/T | Worldsemi | LED_WS2812B_PLCC4_5.0x5.0mm_P3.2mm | SMD | C2761795
16 | J5 | 1 | USB-C receptacle 16P | USB4105-GF-A-120 | GCT | USB_C_Receptacle_GCT_USB4105-xx-A_16P_TopMnt_Horizontal | SMD | C5184243
17 | L1 | 1 | 6.8uH inductor | APH0630T6R8M | APV | L_Changjiang_FXL0630 | SMD | C5349706
18 | L2 | 1 | 5.6uH inductor | FXL0630-5R6-M | Changjiang Microelectronics | L_Changjiang_FXL0630 | SMD | C475914
19 | L3 | 1 | 10uH 4.5A molded inductor | FXL0630-100-M | cjiang (Changjiang Microelectronics Tech) | L_Changjiang_FXL0630 | SMD | C167223 | CORRECTED - schematic LCSC/MPN still point at the old 22uH ZEMS0420-220M (C41438718, 4.4x4.2mm) after the change to 10uH 4.5A on the FXL0630 7x6.6mm footprint
20 | Q2,Q3,Q5 | 3 | SS8050 NPN 1.5A | SS8050(RANGE:200-350) | Changjiang Microelectronics | SOT-23 | SMD | C2150
21 | R1,R3,R5 | 3 | 100k 1% | 0603WAF1003T5E | UNI-ROYAL | R_0603_1608Metric | SMD | C25803
22 | R2 | 1 | 13.7k 1% | 0603WAF1372T5E | UNI-ROYAL | R_0603_1608Metric | SMD | C22793
23 | R4 | 1 | 22.1k 1% | FRC0603F2212TS | FOJAN | R_0603_1608Metric | SMD | C2960862
24 | R6,R7 | 2 | 5.1k 1% | 0603WAF5101T5E | UNI-ROYAL | R_0603_1608Metric | SMD | C23186
25 | R8,R9,R10,R15,R22,R24,R25 | 7 | 10k 1% | 0603WAF1002T5E | UNI-ROYAL | R_0603_1608Metric | SMD | C25804
26 | R14,R18,R40 | 3 | 4.7k 1% | 0603WAF4701T5E | UNI-ROYAL | R_0603_1608Metric | SMD | C23162
27 | R23 | 1 | 120R 1% | 0603WAF1200T5E | UNI-ROYAL | R_0603_1608Metric | SMD | C22787
28 | R26,R27,R37,R42 | 4 | 330R 1% | 0603WAF3300T5E | UNI-ROYAL(Uniroyal Elec) | R_0603_1608Metric | SMD | C23138 | CORRECTED - schematic LCSC/MPN still point at the 1k part (C21190 / 0603WAF1001T5E) after the value changed to 330R
29 | R38 | 1 | 1k 1% | 0603WAF1001T5E | UNI-ROYAL | R_0603_1608Metric | SMD | C21190
30 | U1 | 1 | ESP32-WROOM-32D-N16 module | ESP32-WROOM-32D-N16 | Espressif | ESP32-WROOM-32D | SMD | C529578
31 | U2,U3 | 2 | LMR51430 buck 4-36V 3A | LMR51430XDDCR | Texas Instruments | SOT-23-6 | SMD | C5185863
32 | U4 | 1 | USBLC6-2SC6 USB ESD array | USBLC6-2SC6 | STMicroelectronics | SOT-23-6 | SMD | C7519
33 | U6 | 1 | CH340C USB-UART | CH340C | WCH | SOIC-16_3.9x9.9mm_P1.27mm | SMD | C84681
34 | U7 | 1 | ULN2803A Darlington driver | ULN2803A | UMW | SOIC-18W_7.5x11.6mm_P1.27mm | SMD | C845537
35 | U9 | 1 | MAX3485AEASA+T RS-485 transceiver | MAX3485AEASA+T | Analog Devices / Maxim | SOIC-8_3.9x4.9mm_P1.27mm | SMD | C94609
36 | Buzzer1 | 1 | TMB12A05 buzzer 5V | TMB12A05 | Huaneng | Buzzer_12x9.5RM7.6 | THT | C96093
37 | J1,J7 | 2 | Screw terminal 2P 5.00mm | MX126-5.0-02P-GN01-Cu-S-A | MAX / MaiXu | TerminalBlock_MaiXu_MX126-5.0-02P_1x02_P5.00mm | THT | C5188434
38 | J2,J3,J4,J6,J8,J9,J10,J11 | 8 | Screw terminal 3P 5.00mm | MX126-5.0-03P-GN01-Cu-S-A | MAX / MaiXu | TerminalBlock_MaiXu_MX126-5.0-03P_1x03_P5.00mm | THT | C5188435
39 | J12 | 1 | Screw terminal 4P 5.00mm | MX126-5.0-04P-GN01-Cu-S-A | MaiXu | TerminalBlock_MaiXu_MX126-5.0-04P_1x04_P5.00mm | THT |  | NO LCSC - no 4P 5.0mm block stocked. Gang two 2P (C5188434) or source locally. THT, hand-fitted
40 | JP1 | 1 | Pin header 1x2 2.54mm | PZ254V-11-02P | XFCN | PinHeader_1x02_P2.54mm_Vertical | THT | C492401
41 | K2,K3,K4,K5,K6,K7,K8,K9 | 8 | SRD-S-105D relay SPDT 5V | SRD-S-105D | SANYOU | Relay_SPDT_SANYOU_SRD_Series_Form_C | THT | C276432
42 | Q1 | 1 | IRF4905 P-ch MOSFET | IRF4905PBF | Infineon | TO-220-3_Vertical | THT | C2564
43 | SW1,SW2,SW3 | 3 | Tact switch 6mm THT | TS-1102-4316 | SOFNG | SW_PUSH_6mm | THT | C111374

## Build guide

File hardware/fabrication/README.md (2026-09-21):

# Fabrication

Files in this directory are generated from `hardware/kicad/esp32-relay-controller.kicad_pcb` (rev 1). Regenerate them with the commands at the bottom if you change the board.

## What's here

| File | Purpose |
|---|---|
| `esp32-relay-controller-gerbers.zip` | Bare-board package: 7 gerber layers + 2 Excellon drill files. Upload this as-is. |
| `gerbers/` | The same files unzipped |
| `BOM.csv` | Master BOM — all 97 fitted parts (72 SMD + 25 THT), with description, MPN, manufacturer, footprint, type, LCSC number |
| `BOM-JLCPCB.csv` | SMD only, JLCPCB's expected columns (`Comment, Designator, Footprint, LCSC Part #`) |
| `BOM-PCBWay.csv` | SMD only, MPN-first (PCBWay quotes off manufacturer part number) |
| `CPL.csv` | SMD pick-and-place, 72 rows, `Designator, Mid X, Mid Y, Layer, Rotation`, millimetres. Works for both fabs. |

The three BOMs and the CPL were cross-validated against the board: every SMD reference appears in both the BOM and the CPL exactly once.

## Board parameters

| | |
|---|---|
| Size | 124.75 × 68 mm, rounded corners |
| Layers | 2 |
| Thickness | 1.6 mm |
| Copper | 1 oz (35 µm) |
| Min track / space | 0.20 / 0.15 mm |
| Min drill | 0.30 mm |
| Vias | 0.5 / 0.3 mm (annular 0.1 mm) |
| Surface finish | HASL is fine; ENIG if you want nicer pads under the ESP32 |
| Solder mask | Any colour. Black is what the renders show. |

Everything is inside standard 2-layer capability at JLCPCB and PCBWay.

## Ordering

### Bare PCB

Upload `esp32-relay-controller-gerbers.zip`. Nothing special to select.

### SMD assembly

**JLCPCB:** `BOM-JLCPCB.csv` + `CPL.csv`. All 35 lines carry LCSC part numbers that exist in JLC's assembly catalogue as of Sep 2026. Top side only.

**PCBWay:** `BOM-PCBWay.csv` + `CPL.csv`. LCSC numbers are included as a reference column but PCBWay sources by MPN.

Expect a DFM query on the USB-C connector: the GCT USB4105 footprint puts its two NPTH pegs 0.194 mm from the adjacent ground pads, which is under the 0.25 mm some fabs list. It's the stock footprint's own geometry and is built routinely — accept as-is.

After upload, **check the rotation preview.** KiCad and the fabs disagree on the zero-rotation reference for some packages (SOT-23, SOIC, electrolytics are the usual ones). The CPL carries correct KiCad values; the fab's preview will show anything that needs a 90° or 180° nudge, and that's corrected in their web UI, not in the file.

### Gerber / CPL origin

Both were exported against the **page origin** (not the drill/place origin). If you re-export one, re-export both the same way or the placement won't line up.

## Hand-fitted parts

The 25 through-hole parts are excluded from the assembly BOMs and CPL. All are in `BOM.csv` with LCSC numbers:

| Qty | Part | Refs | LCSC |
|---|---|---|---|
| 8 | SRD-S-105D relay, SPDT 5 V | K2–K9 | C276432 |
| 8 | Screw terminal 3-way, 5.00 mm | J2, J3, J4, J6, J8, J9, J10, J11 | C5188435 |
| 2 | Screw terminal 2-way, 5.00 mm | J1, J7 | C5188434 |
| 1 | Screw terminal 4-way, 5.00 mm | J12 | — (see note) |
| 1 | IRF4905 P-MOSFET, TO-220 | Q1 | C2564 |
| 1 | TMB12A05 active buzzer, 5 V | Buzzer1 | C96093 |
| 3 | 6 mm tact switch | SW1, SW2, SW3 | C111374 |
| 1 | 1×2 pin header, 2.54 mm | JP1 | C492401 |

**J12:** the 4-way MX126-5.0-04P was not stocked at LCSC at the time of writing. Two of the 2-way blocks (C5188434) butt together at the correct 5 mm pitch, or source any 4-way 5.00 mm block locally.

Q1 mounts vertically with no heatsink; at the board's current it dissipates single-digit milliwatts.

## Safe substitutions

- Any 0603 resistor of the same value and 1 % tolerance
- Any 0603/0805 MLCC of the same value, ≥ the stated voltage, X5R or X7R
- `CUS10S30` → any 30 V / 1 A Schottky in SOD-323
- `1N4148WT-7` → any 1N4148 in SOD-523 (D1 carries ≤ 60 mA)
- `SS8050` → any SOT-23 NPN with h<sub>FE</sub> ≥ 100 at 30 mA
- `SRD-S-105D` → SRD-05VDC-SL-C or any SRD-series 5 V Form C relay (same footprint)
- `WS2812B-B/T` → any 5050 4-pin WS2812B variant; **check pin 1 against the datasheet**, some revisions differ

Do not substitute without checking:

- `SMBJ18CA` — must be the bidirectional (`CA`) part; a unidirectional one ahead of the reverse-polarity FET shorts a reversed supply
- `BZX84-C16` — must be 16 V; it clamps the FET gate below its ±20 V limit
- `SM712` — the asymmetric ±7/12 V RS-485 array specifically; a symmetric TVS clips the bus's common-mode range
- `MAX3485` — must be a 3.3 V transceiver (the 5 V MAX485 will not work on this rail)
- `FXL0630-100-M` — anything replacing L3 needs ≥ 3 A continuous rating; it carries the field-bus current

## Regenerating these files

From `hardware/kicad/`:

```sh
kicad-cli pcb export gerbers --layers F.Cu,B.Cu,F.Mask,B.Mask,F.Silkscreen,B.Silkscreen,Edge.Cuts \
    --no-protel-ext --subtract-soldermask -o ../fabrication/gerbers/ esp32-relay-controller.kicad_pcb

kicad-cli pcb export drill --format excellon --excellon-separate-th --drill-origin absolute \
    -o ../fabrication/gerbers/ esp32-relay-controller.kicad_pcb

kicad-cli pcb export pos --format csv --units mm --side both --smd-only --exclude-dnp \
    -o ../fabrication/pos.csv esp32-relay-controller.kicad_pcb
# then rename columns to Designator / Mid X / Mid Y / Layer / Rotation and normalise rotation to 0–360
```

**Refill zones before plotting** (`B` in the PCB editor, or `--check-zones` on the CLI export). The CLI does not refill by default, and a stale fill plots exactly as saved.

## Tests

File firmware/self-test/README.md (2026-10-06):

# Hardware self-test

Bring-up firmware for a freshly assembled board. It exercises every fitted
component and prints a pass/fail report over USB serial.

No libraries are needed beyond the Arduino-ESP32 core — the WS2812B is driven
by the core's built-in `neopixelWrite()`, so there is no NeoPixel or FastLED
dependency.

---

## Build and flash

With [PlatformIO](https://platformio.org/):

```bash
cd firmware/self-test
pio run -t upload -t monitor
```

Or open `self-test.ino` in the Arduino IDE, select **ESP32 Dev Module**, set
flash size to **16 MB (128 Mb)**, and upload.

Either way the serial monitor runs at **115200 baud**.

> **Upload speed.** `platformio.ini` sets **1500000**, which flashes the 300 kB
> image in 1.6 s. Note that **921600 fails on this board while 1500000 works** —
> it is not a speed limit. See [below](#finding-the-ch340c-cannot-express-921600).

---

## What happens when you flash it

Nothing to type and no serial command to remember. On boot the board:

1. Flashes the status LED red, green, blue and beeps once — proof of life for
   someone watching the board rather than a terminal. If you see and hear that,
   the 5 V rail, the WS2812B and the buzzer are all alive.
2. Runs the passive checks (below) and prints them.
3. Counts down five seconds, blinking the LED once a second, then **starts the
   full sweep by itself**.

Press any key during the countdown to get the menu instead and drive the tests
one at a time. At the end the report asks you to confirm what you saw; if
nobody answers within 30 s it stops waiting, marks those checks `??` and prints
the report anyway, so the sketch is usable with no terminal attached at all.

> **It energises all eight relays on every boot.** Fine on a bare board, which
> is what it is for — but don't leave this firmware on a board wired to loads
> you care about.

---

## Applying power

Apply **12 V to J1** before running the relay, buzzer or LED tests.

USB VBUS is diode-ORed into the 3.3 V regulator only, so the MCU, the CH340C
and the MAX3485 all run happily from the USB cable alone — but the 5 V rail
that feeds the relay coils, the buzzer and the WS2812B does not. On USB alone
those three tests run to completion and report success while nothing physically
happens. That is by design, not a fault.

---

## Passive checks

These have no side effects, so they run before the countdown, every boot:

| Check | What a pass proves |
|---|---|
| 3.3 V rail, MCU alive | U3 regulating, module running, crystal ok |
| USB-C, CH340C, UART0 | Connector, ESD array, bridge, GPIO1/3 routing, auto-reset |
| MAX3485 RO idles high | Transceiver powered, RO routed to GPIO16, and the 330 Ω fail-safe bias pair (R26/R27) fitted the right way round |
| Input 1 (J7) reads open | The 10 k pull-up on GPIO34 is fitted |
| User button reads released | The 10 k pull-down on GPIO35 is fitted |
| I²C bus scan | SDA and SCL are not shorted to each other or to a rail |

A `FAIL` on the RO check means the transceiver is unpowered, the bias resistors
are missing, or A and B are swapped or shorted.

---

## The menu

Press any key during the boot countdown to land here instead of running the
sweep. Everything that moves, sounds or lights up is also on the menu
individually, because only a human can confirm that a relay actually clicked.

```
1  WS2812B status LED          6  input monitor (live)
2  buzzer                      7  RS-485 send / listen
3  relays one at a time        8  I2C scan
4  all relays on (2 s)         r  print report
5  relay chase                 0  everything off
a  run every test in order     ?  this menu
```

Any key aborts a running test. `0` forces every output off.

**Test 3** is the one worth running carefully. It walks the bank one relay at a
time and prints the silkscreen number, screw terminal, relay designator,
ULN2803A channel and GPIO for each, so you can follow it on the board. The
silkscreen order is not the GPIO order and not the designator order, so this is
what actually validates the mapping end to end:

| Silk | Terminal | Relay | ULN | GPIO |
|---|---|---|---|---|
| 1 | J3 | K2 | IN2 | 14 |
| 2 | J9 | K5 | IN6 | 19 |
| 3 | J11 | K4 | IN8 | 25 |
| 4 | J2 | K9 | IN1 | 13 |
| 5 | J10 | K3 | IN7 | 23 |
| 6 | J6 | K8 | IN4 | 33 |
| 7 | J4 | K6 | IN3 | 32 |
| 8 | J8 | K7 | IN5 | 18 |

**Test 4** energises all eight coils at once: 8 × 71.4 mA = 571 mA off the 5 V
rail and about 0.5 W in the ULN2803A. The LMR51430 is rated 3 A, so this is
comfortable — it is there to catch a weak rail or a marginal coil, not to
stress anything. If the board resets, the report will say `BROWNOUT` as the
reset reason next time it boots.

**Test 7** sends five frames at 9600 8N1 and then listens for five seconds.
With nothing attached to J12, "nothing received" is the expected result.

The LED is left as a standing verdict after a report: dim green for all pass,
dim amber if something was never run, dim red for any failure.

---

## Bring-up results, rev 1

First assembled board, 6 Oct 2026. ESP32-D0WD rev 1.1, 16 MB flash.

```
 [PASS] 3.3 V rail / MCU alive     you are reading this
 [PASS] USB-C + CH340C + UART0     this serial link
 [PASS] RS-485 receiver idle       RO high, bias ok   (20/20 samples)
 [PASS] Input 1 (J7) readable      pull-up ok, open
 [PASS] User button (SW3)          pull-down ok
 [PASS] I2C bus scan               bus idle, nothing fitted
 [PASS] WS2812B status LED         operator confirmed
 [PASS] Buzzer                     operator confirmed
 [PASS] Relays 1-8 individually    operator confirmed
 [PASS] Relays all on (5 V load)   operator confirmed
```

Everything fitted on the board works. One firmware-level finding came out of
the exercise, described below.

---

## Finding: RO floats during transmit

The first version of test 7 reported ~5 bytes of nonsense received per
transmitted frame, with **nothing attached to J12 and JP1 open**. With no node
on the bus, those bytes could only be self-generated.

It is not the unterminated stub, and not a truncated turn-around. DE and RE̅
are tied together on GPIO2, so enabling the driver also *disables the
receiver* — and a disabled MAX3485 drives RO to **high impedance**. There is no
pull-up on RO in rev 1, so GPIO16 floats for the entire duration of every
transmission (~19 ms for an 18-byte frame at 9600 baud) and the UART clocks in
phantom bytes from the crosstalk off the adjacent DI line.

Lengthening the mark hold before dropping DE changed nothing — 26 bytes before,
26 after. Enabling the ESP32's internal pull-up on GPIO16 took it to **zero**:

```c
Serial2.begin(9600, SERIAL_8N1, RS485_RX_GPIO, RS485_TX_GPIO);
gpio_set_pull_mode((gpio_num_t)RS485_RX_GPIO, GPIO_PULLUP_ONLY);
```

`Serial2.begin()` leaves the RX pin with no pull, so this has to be set after
it. Any firmware for this board wants those two lines together; without them a
receive buffer fills with garbage on every turn-around and a protocol parser
has to resynchronise constantly.

The hardware fix for rev 2 is a 10 kΩ pull-up from RO to 3.3 V, which is what
most RS-485 reference designs fit for exactly this reason. It is in the
[rev 2 backlog](../../docs/design-notes.md#rev-2-backlog).

---

## Finding: the CH340C cannot express 921600

`pio run -t upload` at 921600 dies right after the baud change:

```
Changing baud rate to 921600
Changed.
A fatal error occurred: Unable to verify flash chip connection
  (Invalid head of packet (0xE0): Possible serial noise or corruption.)
```

"Serial noise" is esptool guessing, and it is wrong. Sweeping the rate shows
the failures are not above a threshold — they are at *particular* rates:

| Requested | n | Actual | Error | Result |
|---|---|---|---|---|
| 115200 | 52 | 115385 | +0.16 % | ok |
| 230400 | 26 | 230769 | +0.16 % | ok |
| 460800 | 13 | 461538 | +0.16 % | ok |
| 576000 | 10 | 600000 | **+4.17 %** | **fails** |
| 600000 | 10 | 600000 | 0.00 % | ok |
| 750000 | 8 | 750000 | 0.00 % | ok |
| 921600 | 7 | 857143 | **−6.99 %** | **fails** |
| 1000000 | 6 | 1000000 | 0.00 % | ok |
| 1200000 | 5 | 1200000 | 0.00 % | ok |
| 1500000 | 4 | 1500000 | 0.00 % | ok |

750000 works and 576000 does not. 1500000 works and 921600 does not. Nothing
about that is a signal-integrity ceiling.

The CH340C derives its baud rate by dividing a 48 MHz clock through a
prescaler and an 8-bit divisor. The measured set of working rates is exactly
**6 000 000 / n** for integer n, which is what you get if the host driver uses
only the coarse prescaler setting. This board enumerates as
`/dev/cu.usbserial-*`, i.e. Apple's built-in CH34x driver — WCH's own driver
names the device `wchusbserial` and may well divide more finely. The 6 MHz/n
set is therefore a property of this host, not of the board, and the table
above is worth re-measuring on Linux or with the vendor driver.

Either way the mechanism is plain: 921600 is unreachable, the driver lands on
857143 instead, and a receiver running 7 % slow samples the last data bit and
the stop bit in the wrong bit cell. An 8N1 UART tolerates roughly ±2 %. That
is also why the corrupted byte was `0xE0`: SLIP frames start with `0xC0`
(`11000000`), and `0xE0` is `11100000` — the same byte with the sampling point
slipped one cell into the idle-high line.

Practical rule for this board: pick a rate that divides 6 MHz exactly.
1500000 is the fastest that works and flashes the 300 kB image in 1.6 s,
against 4.3 s at 460800 — both hash-verified.

---

## Licence

`SPDX-License-Identifier: CERN-OHL-P-2.0` — see [`LICENSE`](../../LICENSE).

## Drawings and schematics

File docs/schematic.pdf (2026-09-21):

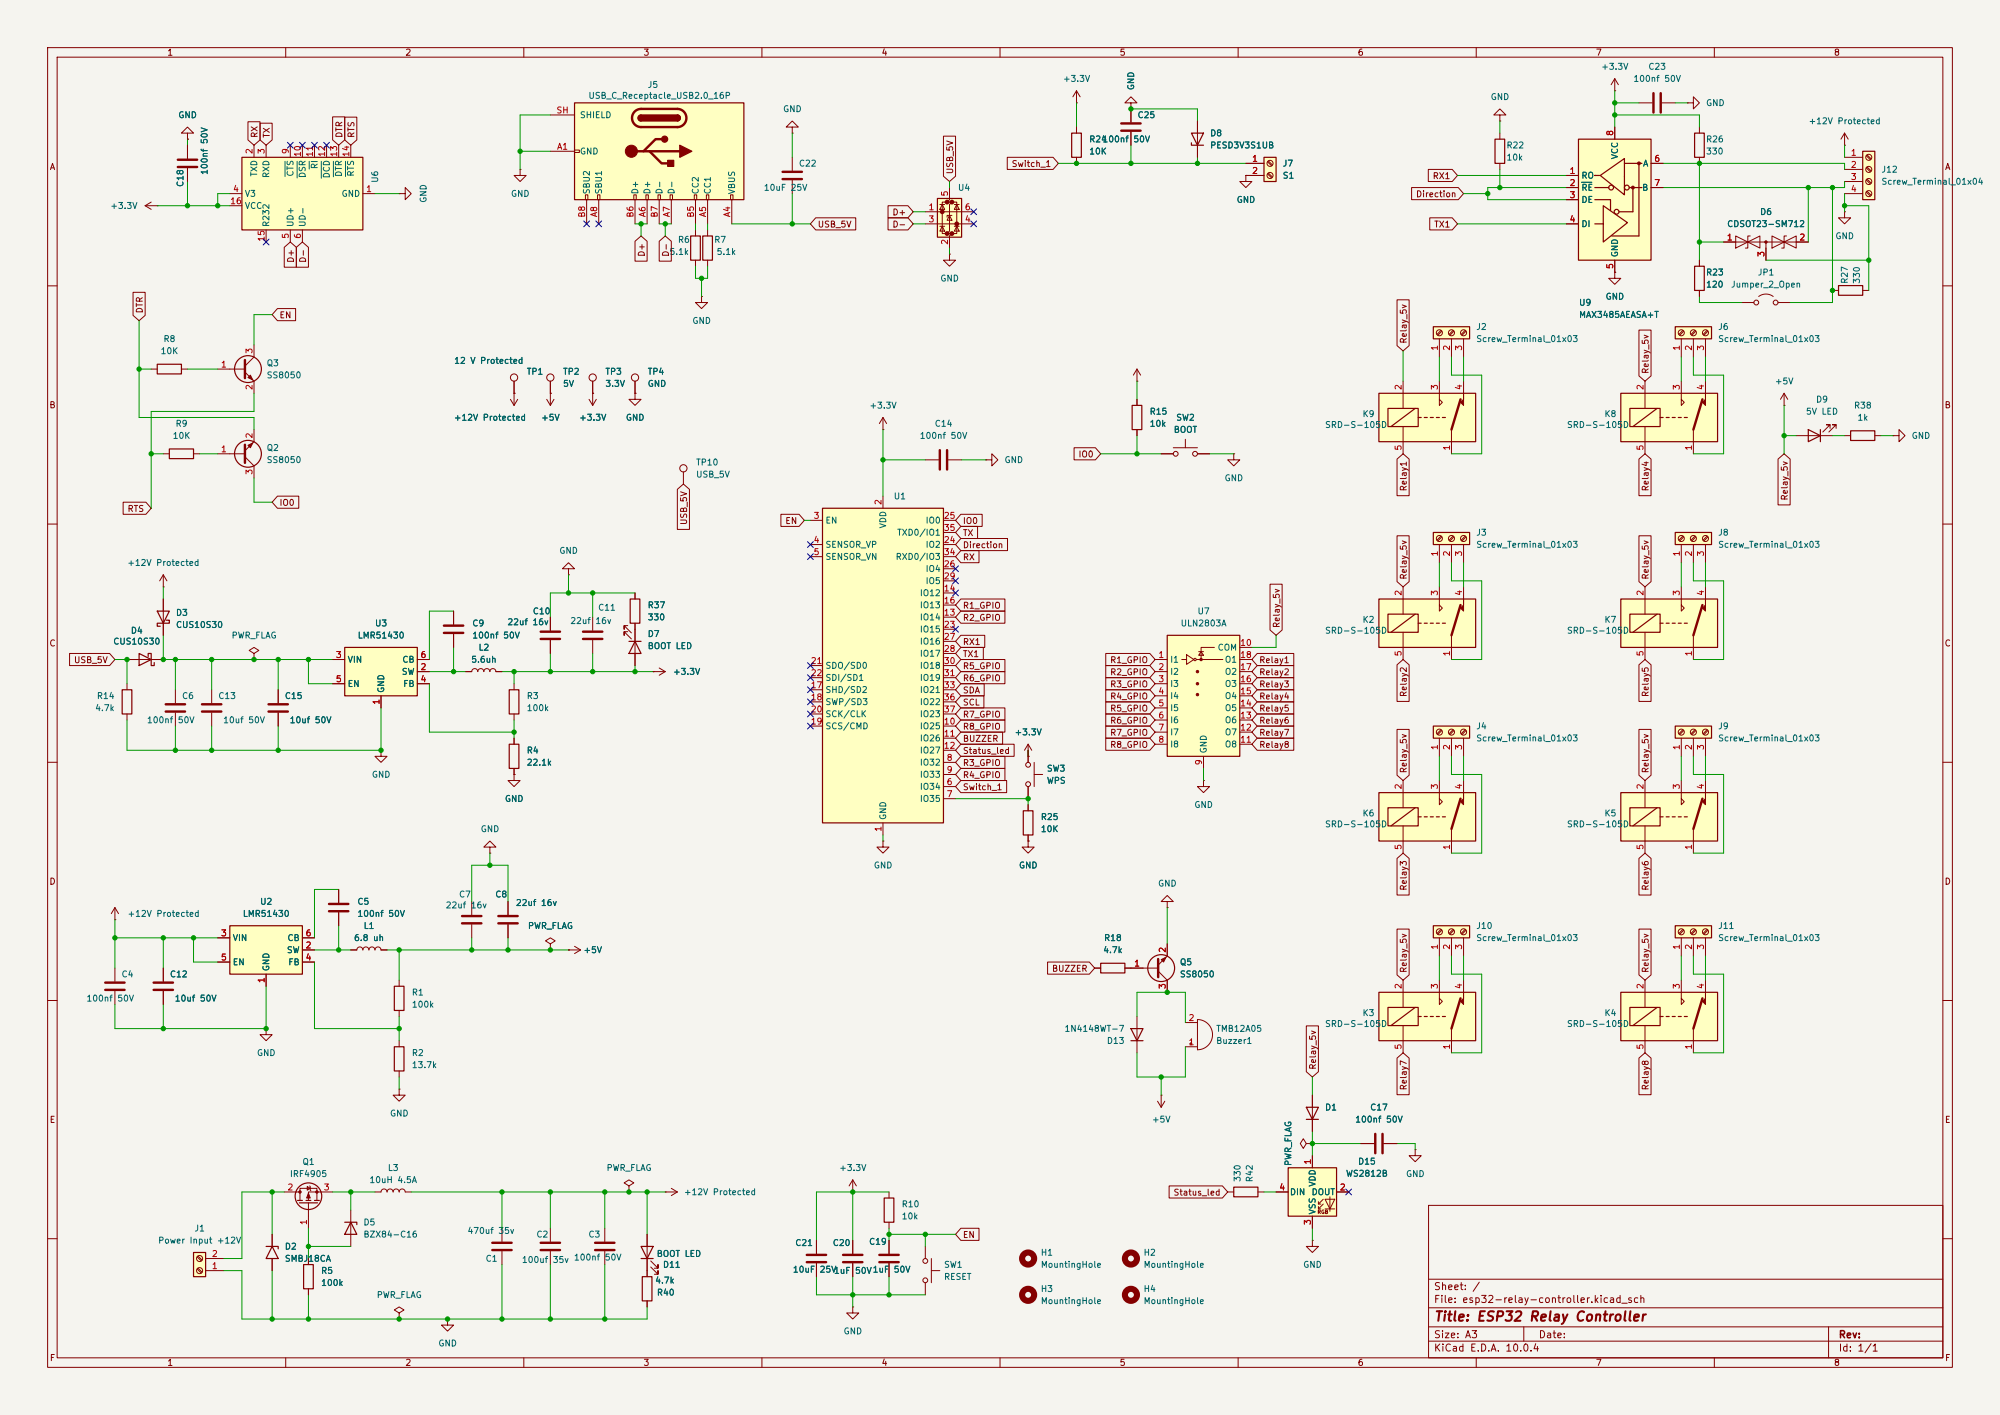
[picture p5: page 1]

9 DSR 10 RI 11 DCD 12 DTR 13 RTS 14 R232 15

Size: A3 | Rev: | F Date:
KiCad E.D.A. 10.0.4 | Id: 1/1

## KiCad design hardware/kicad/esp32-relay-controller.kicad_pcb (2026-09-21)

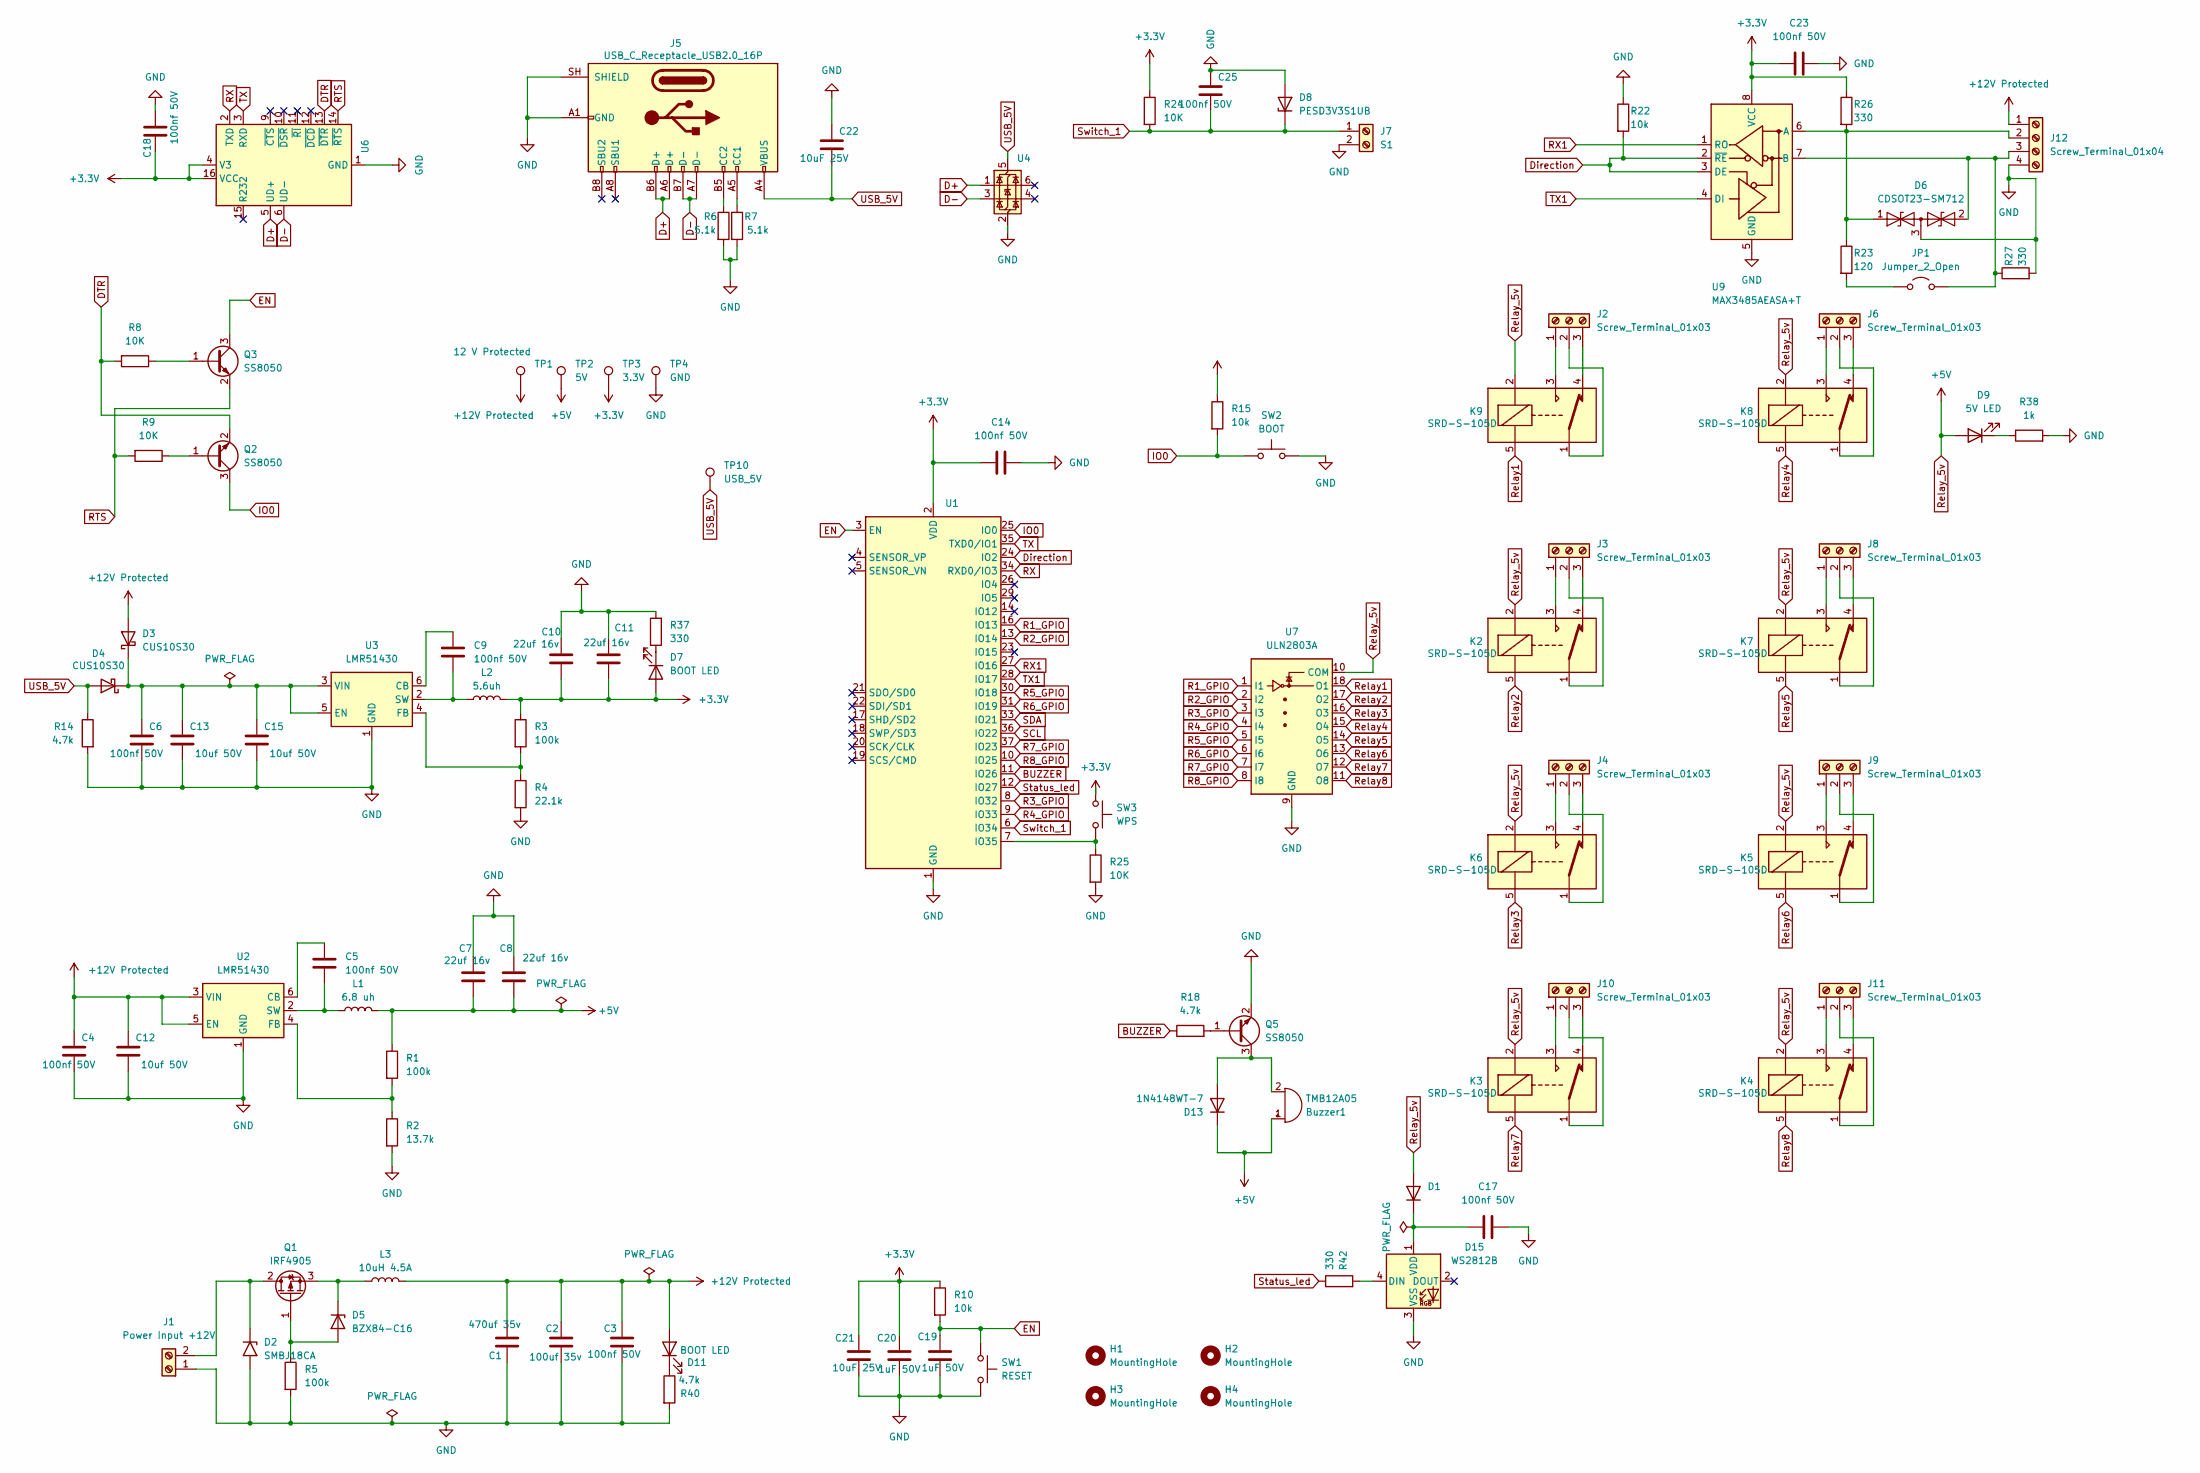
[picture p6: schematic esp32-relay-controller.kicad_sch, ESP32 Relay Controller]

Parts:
Buzzer1: TMB12A05; Buzzer_12x9.5RM7.6; MPN TMB12A05; LCSC C96093
C1: 470uf 35v; CP_Elec_10x10.5; MPN RVT1V471M1010 470UF 35V; LCSC C976030
C2: 100uf 35v; CP_Elec_6.3x7.7; MPN JBLM2101M035C070RTM 100UF 35V; LCSC C19270708
C3, C4, C5, C6, C9, C14, C17, C18, C23, C25: 100nf 50V; C_0603_1608Metric; MPN CL10B104KB8NNNC; LCSC C1591
C7, C8, C10, C11: 22uf 16v; C_0805_2012Metric; MPN CL21A226KOQNNNE; LCSC C296720
C12, C13, C15: 10uf 50V; C_0805_2012Metric; MPN GRM21BR61H106KE43L; LCSC C440198
C19, C20: 1uF 50V; C_0603_1608Metric; MPN CL10A105KB8NNNC; LCSC C15849
C21, C22: 10uF 25V; C_0603_1608Metric; MPN CL10A106MA8NRNC; LCSC C96446
D1, D13: 1N4148WT-7; D_SOD-523; MPN 1N4148WT-7; LCSC C83482
D2: SMBJ18CA; D_SMB; MPN SMBJ18CA; LCSC C2938922
D3, D4: CUS10S30; D_SOD-323; MPN CUS10S30; LCSC C27636107
D5: BZX84-C16; SOT-23; MPN BZX84-C16,235; LCSC C550938
D6: CDSOT23-SM712; SOT-23; MPN CDSOT23-SM712; LCSC C404012
D7, D11: BOOT LED; LED_0201_0603Metric; MPN CT-0201URC-P4; LCSC C52675906
D8: PESD3V3S1UB; D_SOD-523; MPN PESD3V3S1UB; LCSC C2912529
D9: 5V LED; LED_0201_0603Metric; MPN CT-0201URC-P4; LCSC C52675906
D15: WS2812B; LED_WS2812B_PLCC4_5.0x5.0mm_P3.2mm; MPN WS2812B-B/T; LCSC C2761795
H1, H2, H3, H4: MountingHole; MountingHole_2mm; MPN PCB feature
J1: Power Input +12V; TerminalBlock_MaiXu_MX126-5.0-02P_1x02_P5.00mm; MPN MX126-5.0-02P-GN01-Cu-S-A; LCSC C5188434
J2, J3, J4, J6, J8, J9, J10, J11: Screw_Terminal_01x03; TerminalBlock_MaiXu_MX126-5.0-03P_1x03_P5.00mm; MPN MX126-5.0-03P-GN01-Cu-S-A; LCSC C5188435
J5: USB_C_Receptacle_USB2.0_16P; USB_C_Receptacle_GCT_USB4105-xx-A_16P_TopMnt_Horizontal; MPN USB4105-GF-A-120; LCSC C5184243
J7: S1; TerminalBlock_MaiXu_MX126-5.0-02P_1x02_P5.00mm; MPN MX126-5.0-02P-GN01-Cu-S-A; LCSC C5188434
J12: Screw_Terminal_01x04; TerminalBlock_MaiXu_MX126-5.0-04P_1x04_P5.00mm; MPN MX126-5.0-04P-GN01-Cu-S-A
JP1: Jumper_2_Open; PinHeader_1x02_P2.54mm_Vertical; MPN PZ254V-11-02P; LCSC C492401
K2, K3, K4, K5, K6, K7, K8, K9: SRD-S-105D; Relay_SPDT_SANYOU_SRD_Series_Form_C; MPN SRD-S-105D; LCSC C276432
L1: 6.8 uh; L_Changjiang_FXL0630; MPN APH0630T6R8M; LCSC C5349706
L2: 5.6uh; L_Changjiang_FXL0630; MPN FXL0630-5R6-M; LCSC C475914
L3: 10uH 4.5A; L_Changjiang_FXL0630; MPN ZEMS0420-220M; LCSC C41438718
Q1: IRF4905; TO-220-3_Vertical; MPN IRF4905PBF; LCSC C2564
Q2, Q3, Q5: SS8050; SOT-23; MPN SS8050(RANGE:200-350); LCSC C2150
R1, R3, R5: 100k; R_0603_1608Metric; MPN 0603WAF1003T5E; LCSC C25803
R2: 13.7k; R_0603_1608Metric; MPN 0603WAF1372T5E; LCSC C22793
R4: 22.1k; R_0603_1608Metric; MPN FRC0603F2212TS; LCSC C2960862
R6, R7: 5.1k; R_0603_1608Metric; MPN 0603WAF5101T5E; LCSC C23186
R8, R9, R24, R25: 10K; R_0603_1608Metric; MPN 0603WAF1002T5E; LCSC C25804
R10, R15, R22: 10k; R_0603_1608Metric; MPN 0603WAF1002T5E; LCSC C25804
R14, R18, R40: 4.7k; R_0603_1608Metric; MPN 0603WAF4701T5E; LCSC C23162
R23: 120; R_0603_1608Metric; MPN 0603WAF1200T5E; LCSC C22787
R26, R27, R42: 330; R_0603_1608Metric; MPN 0603WAF3300T5E; LCSC C23138
R37: 330; R_0603_1608Metric; MPN 0603WAF1001T5E; LCSC C23138
R38: 1k; R_0603_1608Metric; MPN 0603WAF1001T5E; LCSC C21190
SW1: RESET; SW_PUSH_6mm; MPN TS-1102-4316; LCSC C111374
SW2: BOOT; SW_PUSH_6mm; MPN TS-1102-4316; LCSC C111374
SW3: WPS; SW_PUSH_6mm; MPN TS-1102-4316; LCSC C111374
TP1: 12 V Protected; TestPoint_Pad_D1.5mm; MPN PCB feature
TP2: 5V; TestPoint_Pad_D1.5mm; MPN PCB feature
TP3: 3.3V; TestPoint_Pad_D1.5mm; MPN PCB feature
TP4: GND; TestPoint_Loop_D2.50mm_Drill1.0mm; MPN Formed tinned wire loop
TP10: USB_5V; TestPoint_Pad_D1.5mm; MPN PCB feature
U1: ESP32-WROOM-32D; MPN ESP32-WROOM-32D-N16; LCSC C529578
U2, U3: LMR51430; SOT-23-6; MPN LMR51430XDDCR; LCSC C5185863
U4: USBLC6-2SC6; SOT-23-6; MPN USBLC6-2SC6; LCSC C7519
U6: CH340C; SOIC-16_3.9x9.9mm_P1.27mm; MPN CH340C; LCSC C84681
U7: ULN2803A; SOIC-18W_7.5x11.6mm_P1.27mm; MPN ULN2803A; LCSC C845537
U9: MAX3485AEASA+T; SOIC-8_3.9x4.9mm_P1.27mm; MPN MAX3485AEASA+T; LCSC C94609

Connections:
+3.3V: C10.2, C11.2, C14.1, C18.2, C20.1, C21.1, C23.1, D7.2 (A), L2.2, R3.1, R10.1, R15.1, R24.1, R26.1, SW3.1, TP3.1 (1_1), U1.2 (VDD), U6.4 (V3), U6.16 (VCC), U9.8 (VCC)
+12V Protected: C1.1, C2.1, C3.1, C4.1, C12.1, D3.2 (A), D11.2 (A), J12.1, L3.2, TP1.1 (1_1), U2.3 (VIN), U2.5 (EN)
BUZZER: R18.1, U1.11 (IO26)
D+: J5.A6 (D+), J5.B6 (D+), U4.1 (I/O1), U6.5 (UD+)
D-: J5.A7 (D-), J5.B7 (D-), U4.3 (I/O2), U6.6 (UD-)
DTR: Q2.2 (E), R8.2, U6.13 (~DTR)
Direction: R22.2, U1.24 (IO2), U9.2 (~RE), U9.3 (DE)
EN: C19.1, Q3.3 (C), R10.2, SW1.1, U1.3 (EN)
GND: C1.2, C2.2, C3.2, C4.2, C6.2, C7.1, C8.1, C10.1, C11.1, C12.2, C13.2, C14.2, C15.2, C17.2, C18.1, C19.2, C20.2, C21.2, C22.1, C23.2, C25.1, D2.2 (A2), D6.3 (common), D8.2 (A), D15.3 (VSS), J1.1, J5.A1 (GND), J5.A12 (GND), J5.B1 (GND), J5.B12 (GND), J5.SH (SHIELD), J7.2, J12.4, Q5.2 (E), R2.2, R4.2, R5.2, R6.2, R7.2, R14.2, R22.1, R25.2, R27.2, R37.2, R38.2, R40.2, SW1.2, SW2.2, TP4.1 (1_1), U1.1 (GND), U1.15 (GND), U1.38 (GND), U1.39 (GND), U2.1 (GND), U3.1 (GND), U4.2 (GND), U6.1 (GND), U7.9 (GND), U9.5 (GND)
IO0: Q2.3 (C), R15.2, SW2.1, U1.25 (IO0)
unnamed: Buzzer1.2 (-), D13.2 (A), Q5.3 (C)
unnamed: C17.1, D1.1 (K), D15.1 (VDD)
unnamed: D2.1 (A1), J1.2, Q1.2 (D)
unnamed: C6.1, C13.1, C15.1, D3.1 (K), D4.1 (K), U3.3 (VIN), U3.5 (EN)
unnamed: D5.1 (A), Q1.1 (G), R5.1
unnamed: D5.3 (K), L3.1, Q1.3 (S)
unnamed: D6.1 (A1), J12.2, R23.1, R26.2, U9.6 (A)
unnamed: D6.2 (A2), J12.3, JP1.2 (B), R27.1, U9.7 (B)
unnamed: D7.1 (K), R37.1
unnamed: D9.1 (K), R38.1
unnamed: D11.1 (K), R40.1
unnamed: D15.4 (DIN), R42.2
unnamed: J2.1, K9.3
unnamed: J2.2, K9.1
unnamed: J2.3, K9.4
unnamed: J3.1, K2.3
unnamed: J3.2, K2.1
unnamed: J3.3, K2.4
unnamed: J4.1, K6.3
unnamed: J4.2, K6.1
unnamed: J4.3, K6.4
unnamed: J5.A5 (CC1), R7.1
unnamed: J5.B5 (CC2), R6.1
unnamed: J6.1, K8.3
unnamed: J6.2, K8.1
unnamed: J6.3, K8.4
unnamed: J8.1, K7.3
unnamed: J8.2, K7.1
unnamed: J8.3, K7.4
unnamed: J9.1, K5.3
unnamed: J9.2, K5.1
unnamed: J9.3, K5.4
unnamed: J10.1, K3.3
unnamed: J10.2, K3.1
unnamed: J10.3, K3.4
unnamed: J11.1, K4.3
unnamed: J11.2, K4.1
unnamed: J11.3, K4.4
unnamed: JP1.1 (A), R23.2
unnamed: Q2.1 (B), R9.1
unnamed: Q3.1 (B), R8.1
unnamed: Q5.1 (B), R18.2
unnamed: R25.1, SW3.2, U1.7 (IO35)
unnamed: C5.1, U2.6 (CB)
unnamed: R1.2, R2.1, U2.4 (FB)
unnamed: C5.2, L1.1, U2.2 (SW)
unnamed: C9.1, U3.6 (CB)
unnamed: R3.2, R4.1, U3.4 (FB)
unnamed: C9.2, L2.1, U3.2 (SW)
R1_GPIO: U1.16 (IO13), U7.1 (I1)
R2_GPIO: U1.13 (IO14), U7.2 (I2)
R3_GPIO: U1.8 (IO32), U7.3 (I3)
R4_GPIO: U1.9 (IO33), U7.4 (I4)
R5_GPIO: U1.30 (IO18), U7.5 (I5)
R6_GPIO: U1.31 (IO19), U7.6 (I6)
R7_GPIO: U1.37 (IO23), U7.7 (I7)
R8_GPIO: U1.10 (IO25), U7.8 (I8)
RTS: Q3.2 (E), R9.2, U6.14 (~RTS)
RX: U1.34 (RXD0/IO3), U6.2 (TXD)
RX1: U1.27 (IO16), U9.1 (RO)
Relay1: K9.5, U7.18 (O1)
Relay2: K2.5, U7.17 (O2)
Relay3: K6.5, U7.16 (O3)
Relay4: K8.5, U7.15 (O4)
Relay5: K7.5, U7.14 (O5)
Relay6: K5.5, U7.13 (O6)
Relay7: K3.5, U7.12 (O7)
Relay8: K4.5, U7.11 (O8)
Relay_5v: Buzzer1.1 (+), C7.2, C8.2, D1.2 (A), D9.2 (A), D13.1 (K), K2.2, K3.2, K4.2, K5.2, K6.2, K7.2, K8.2, K9.2, L1.2, R1.1, TP2.1 (1_1), U7.10 (COM)
SCL: U1.36 (IO22)
SDA: U1.33 (IO21)
Status_led: R42.1, U1.12 (IO27)
Switch_1: C25.2, D8.1 (K), J7.1, R24.2, U1.6 (IO34)
TX: U1.35 (TXD0/IO1), U6.3 (RXD)
TX1: U1.28 (IO17), U9.4 (DI)
USB_5V: C22.2, D4.2 (A), J5.A4 (VBUS), J5.A9 (VBUS), J5.B4 (VBUS), J5.B9 (VBUS), R14.1, TP10.1 (1_1), U4.5 (VBUS)

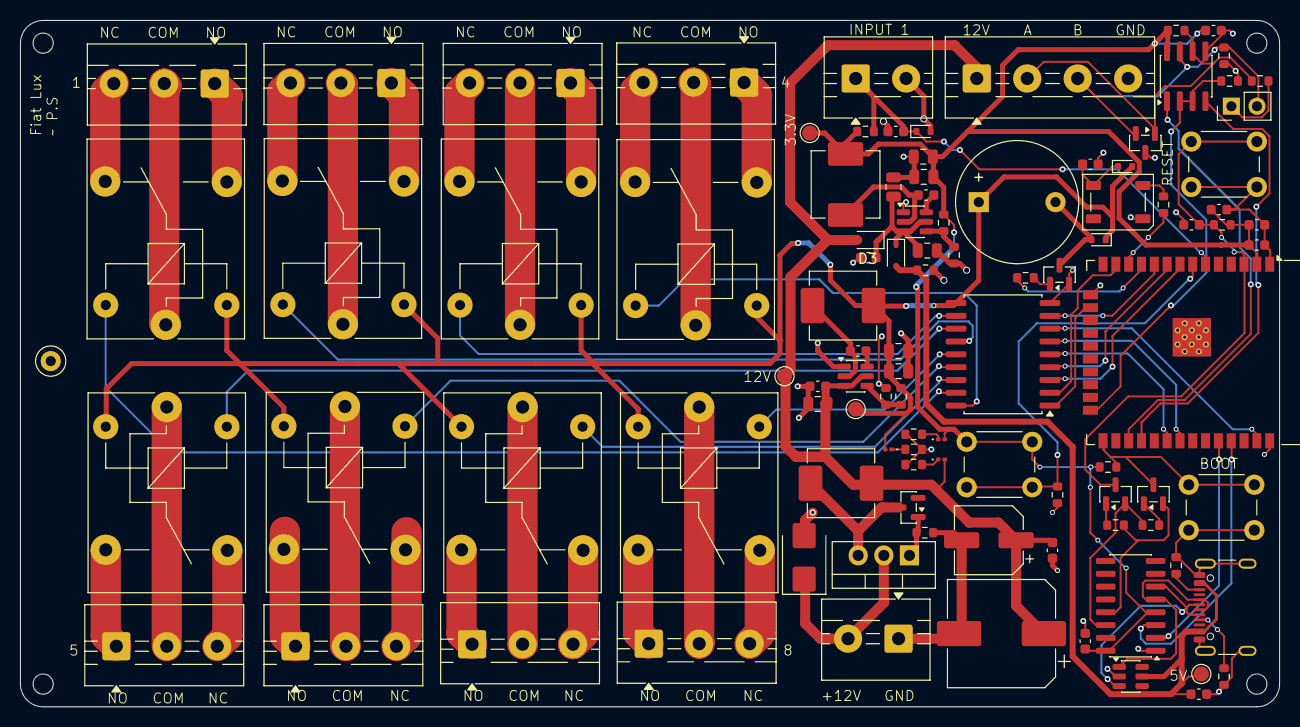
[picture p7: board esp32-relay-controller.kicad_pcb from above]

Board: 2 copper layers, 124.8 x 68.0 mm, 106 parts (0 on the bottom side), 84 nets.

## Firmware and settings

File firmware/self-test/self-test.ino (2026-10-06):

/*
 * ESP32 Relay Controller - hardware self-test
 * ===========================================
 *
 * Bring-up firmware for a freshly assembled rev 1 board. It exercises every
 * fitted component and prints a pass/fail report over the USB serial port.
 *
 *   Serial:  115200 baud, 8N1, over the on-board CH340C (USB-C)
 *
 * On boot it flashes the LED, beeps once, and then starts the full sweep by
 * itself after a five-second countdown - so flashing the board is enough to
 * test it, with no serial terminal and no commands to remember. Press any key
 * during the countdown to get the menu instead and drive the tests one at a
 * time. The report still asks the operator to confirm what they saw, but an
 * unanswered prompt times out rather than wedging the sketch.
 *
 * WARNING: it energises all eight relays on every boot. Don't leave it on a
 * board wired to loads you care about.
 *
 * ---------------------------------------------------------------------------
 * POWER: apply 12 V to J1 before running the relay, buzzer or LED tests.
 * ---------------------------------------------------------------------------
 * USB VBUS is diode-ORed into the 3.3 V regulator only, so the MCU, CH340C and
 * MAX3485 all run from the USB cable - but the 5 V rail that feeds the relay
 * coils, the buzzer and the WS2812B does not. On USB alone those three tests
 * run and report success while nothing physically happens. That is by design,
 * not a fault. See docs/design-notes.md.
 *
 * Dependencies: none beyond the Arduino-ESP32 core (>= 2.0.3, for the built-in
 * neopixelWrite). No NeoPixel or FastLED library needed.
 *
 * SPDX-License-Identifier: CERN-OHL-P-2.0
 */

#include <Arduino.h>
#include <Wire.h>
#include <driver/gpio.h>

/* ========================================================================
 * Pin map - rev 1. Mirrors docs/pinout.md; change both together.
 * ======================================================================== */

#define RELAY_COUNT 8

/* Dwell times for the relay walk. Long enough to watch a contact move and
 * hear it as a separate event, rather than as a blur of clicks. */
static const uint16_t RELAY_ON_MS  = 1200;
static const uint16_t RELAY_OFF_MS =  450;
static const uint16_t CHASE_MS     =  280;

/* Relay coil drives in SILKSCREEN order 1-8, active high into a ULN2803A.
 * The silkscreen order is not the GPIO order and not the relay-designator
 * order, so the test prints all three and you check the board against it. */
static const uint8_t RELAY_GPIO[RELAY_COUNT]   = {   14,   19,   25,   13,   23,   33,   32,   18 };
static const char *const RELAY_REF[RELAY_COUNT]  = { "K2", "K5", "K4", "K9", "K3", "K8", "K6", "K7" };
static const char *const RELAY_TERM[RELAY_COUNT] = { "J3", "J9", "J11", "J2", "J10", "J6", "J4", "J8" };
static const uint8_t RELAY_ULN_IN[RELAY_COUNT] = {    2,    6,    8,    1,    7,    4,    3,    5 };

#define BUZZER_GPIO       26   /* SS8050 NPN, 4k7 base resistor. High = on.   */
#define STATUS_LED_GPIO   27   /* WS2812B DIN through 330R, one pixel         */

#define RS485_TX_GPIO     17   /* -> MAX3485 DI                               */
#define RS485_RX_GPIO     16   /* <- MAX3485 RO                               */
#define RS485_DIR_GPIO     2   /* DE and /RE tied. High = transmit.           */
                               /* Strapping pin: external 10k pull-down keeps */
                               /* it low at boot. Never add an internal pull. */

#define INPUT1_GPIO       34   /* J7 dry contact to GND, ext 10k pull-up.     */
                               /* Closed = LOW. Input-only pin.               */
#define USER_BTN_GPIO     35   /* SW3 "WPS" to 3V3, ext 10k pull-down.        */
                               /* Pressed = HIGH. Input-only pin.             */
#define BOOT_BTN_GPIO      0   /* SW2 "BOOT" to GND, 10k pull-up.             */
                               /* Pressed = LOW.                              */

#define I2C_SDA_GPIO      21   /* Routed, but no pull-ups fitted in rev 1     */
#define I2C_SCL_GPIO      22

/* ========================================================================
 * Test bookkeeping
 * ======================================================================== */

enum Result : uint8_t { R_SKIP = 0, R_PASS, R_FAIL, R_MANUAL };

struct Check {
  const char *name;
  Result      result;
  const char *note;
};

static Check checks[] = {
  { "3.3 V rail / MCU alive",    R_PASS, "you are reading this" },
  { "USB-C + CH340C + UART0",    R_PASS, "this serial link"     },
  { "RS-485 receiver idle",      R_SKIP, ""                     },
  { "Input 1 (J7) readable",     R_SKIP, ""                     },
  { "User button (SW3)",         R_SKIP, ""                     },
  { "I2C bus scan",              R_SKIP, ""                     },
  { "WS2812B status LED",        R_SKIP, "operator confirms"    },
  { "Buzzer",                    R_SKIP, "operator confirms"    },
  { "Relays 1-8 individually",   R_SKIP, "operator confirms"    },
  { "Relays all on (5 V load)",  R_SKIP, "operator confirms"    },
};

enum CheckIdx : uint8_t {
  CHK_RAIL = 0, CHK_USB, CHK_RS485_IDLE, CHK_INPUT1, CHK_USERBTN,
  CHK_I2C, CHK_LED, CHK_BUZZER, CHK_RELAY_EACH, CHK_RELAY_ALL
};

static void mark(CheckIdx i, Result r, const char *note = "") {
  checks[i].result = r;
  if (note[0]) checks[i].note = note;
}

/* ========================================================================
 * Small helpers
 * ======================================================================== */

/* 1 = yes, 0 = no, -1 = nobody answered. Defined under "Serial UI" below. */
static int8_t askYesNo(uint16_t timeout_s = 30);

/* Tests that need a human to confirm them ask directly when run on their own,
 * but stay quiet during the full sweep - stopping for a y/n between every
 * stage defeats the point of watching the board as a whole. The sweep asks
 * once at the end instead. */
static bool g_askOperator = true;

static void confirm(CheckIdx idx, const char *question) {
  if (!g_askOperator) { mark(idx, R_MANUAL, "ran in full sweep"); return; }
  Serial.printf("   %s [y/n]\n", question);
  int8_t a = askYesNo();
  if (a < 0) mark(idx, R_MANUAL, "ran, unconfirmed");
  else       mark(idx, a ? R_PASS : R_FAIL, "operator confirmed");
}

/* Any key during a long test aborts it and drops back to the menu. */
static bool aborted() {
  if (Serial.available()) {
    while (Serial.available()) Serial.read();
    Serial.println("\n  [aborted]");
    return true;
  }
  return false;
}

/* delay() that can be cut short by a keypress. Returns false if aborted. */
static bool waitMs(uint32_t ms) {
  uint32_t t0 = millis();
  while (millis() - t0 < ms) {
    if (aborted()) return false;
    delay(2);
  }
  return true;
}

static void ledOff()                                { neopixelWrite(STATUS_LED_GPIO, 0, 0, 0); }
static void led(uint8_t r, uint8_t g, uint8_t b)     { neopixelWrite(STATUS_LED_GPIO, r, g, b); }

/* Hue 0-255 -> RGB at full saturation. Enough for a rainbow sweep. */
static void hueToRgb(uint8_t h, uint8_t &r, uint8_t &g, uint8_t &b) {
  uint8_t seg = h / 43;            /* 6 segments of 42.6 */
  uint8_t off = (h - seg * 43) * 6;
  switch (seg) {
    case 0:  r = 255;       g = off;       b = 0;         break;
    case 1:  r = 255 - off; g = 255;       b = 0;         break;
    case 2:  r = 0;         g = 255;       b = off;       break;
    case 3:  r = 0;         g = 255 - off; b = 255;       break;
    case 4:  r = off;       g = 0;         b = 255;       break;
    default: r = 255;       g = 0;         b = 255 - off; break;
  }
}

static void relayWrite(uint8_t idx, bool on) {
  digitalWrite(RELAY_GPIO[idx], on ? HIGH : LOW);
}

static void relaysAllOff() {
  for (uint8_t i = 0; i < RELAY_COUNT; i++) relayWrite(i, false);
}

/* Everything to a known-safe state. Called at boot and by the '0' command. */
static void allOutputsOff() {
  relaysAllOff();
  digitalWrite(BUZZER_GPIO, LOW);
  ledOff();
}

/* ========================================================================
 * Passive checks - no side effects, safe to run unattended at boot
 * ======================================================================== */

/* The MAX3485 sits in receive mode at boot (GPIO2 pulled down). The board's
 * fail-safe bias - 330R from 3.3 V to A, 330R from B to GND - holds the idle
 * differential at ~508 mV with one terminator fitted, well over the 200 mV
 * receiver threshold. So RO must sit HIGH. A LOW here means the transceiver
 * is unpowered, the bias resistors are missing, or A/B are swapped or shorted.
 *
 * Read the pin raw, before UART2 claims it. */
static void checkRs485Idle() {
  pinMode(RS485_DIR_GPIO, OUTPUT);
  digitalWrite(RS485_DIR_GPIO, LOW);          /* receive */
  pinMode(RS485_RX_GPIO, INPUT);
  delay(5);

  uint8_t high = 0;
  for (uint8_t i = 0; i < 20; i++) { high += digitalRead(RS485_RX_GPIO); delay(1); }

  Serial.printf("  MAX3485 RO idle ....... %s  (%u/20 samples high)\n",
                high >= 18 ? "HIGH - ok" : "LOW  - CHECK", high);
  if (high >= 18) mark(CHK_RS485_IDLE, R_PASS, "RO high, bias ok");
  else            mark(CHK_RS485_IDLE, R_FAIL, "RO low - transceiver, bias or A/B wiring");
}

static void checkInputs() {
  pinMode(INPUT1_GPIO,   INPUT);   /* no internal pulls on 34/35 anyway */
  pinMode(USER_BTN_GPIO, INPUT);
  pinMode(BOOT_BTN_GPIO, INPUT);
  delay(5);

  bool in1  = digitalRead(INPUT1_GPIO);
  bool user = digitalRead(USER_BTN_GPIO);
  bool boot = digitalRead(BOOT_BTN_GPIO);

  Serial.printf("  Input 1 (J7) .......... %s  (%s)\n",
                in1 ? "HIGH" : "LOW ", in1 ? "contact open" : "contact closed");
  Serial.printf("  User button (SW3) ..... %s  (%s)\n",
                user ? "HIGH" : "LOW ", user ? "pressed" : "released");
  Serial.printf("  BOOT button (SW2) ..... %s  (%s)\n",
                boot ? "HIGH" : "LOW ", boot ? "released" : "pressed");

  /* An idle board should read: J7 high (10k pull-up, nothing connected),
   * SW3 low (10k pull-down), SW2 high (10k pull-up). All three stuck the
   * wrong way with nothing attached points at a missing resistor. */
  mark(CHK_INPUT1,  in1  ? R_PASS : R_MANUAL, in1  ? "pull-up ok, open" : "reads closed");
  mark(CHK_USERBTN, user ? R_MANUAL : R_PASS, user ? "reads pressed"    : "pull-down ok");
}

/* Rev 1 fits no I2C device - the SHT4x was dropped to make room for the
 * RS-485 section - so finding nothing is the expected result, not a failure.
 * The scan is here for when a sensor is added, and it does prove the two
 * pins are not shorted to each other or to a rail. */
static void checkI2c() {
  Wire.begin(I2C_SDA_GPIO, I2C_SCL_GPIO, 100000);
  uint8_t found = 0;
  for (uint8_t addr = 0x08; addr < 0x78; addr++) {
    Wire.beginTransmission(addr);
    if (Wire.endTransmission() == 0) {
      Serial.printf("  I2C device found ...... 0x%02X\n", addr);
      found++;
    }
  }
  if (found == 0) {
    Serial.println("  I2C scan .............. no devices (expected on rev 1)");
    mark(CHK_I2C, R_PASS, "bus idle, nothing fitted");
  } else {
    mark(CHK_I2C, R_PASS, "device(s) responded");
  }
}

/* ========================================================================
 * Active tests - these make noise and move contacts
 * ======================================================================== */

static void testLed() {
  Serial.println("\n-- WS2812B status LED (D15) ------------------------------");
  Serial.println("   Expect: red, green, blue, white, then a rainbow sweep.");
  Serial.println("   Wrong colour order means the pixel is not GRB.");

  struct { const char *name; uint8_t r, g, b; } steps[] = {
    { "red",   255,   0,   0 },
    { "green",   0, 255,   0 },
    { "blue",    0,   0, 255 },
    { "white", 255, 255, 255 },
  };

  for (auto &s : steps) {
    Serial.printf("   %-6s", s.name);
    Serial.flush();
    led(s.r, s.g, s.b);
    if (!waitMs(700)) { ledOff(); return; }
    Serial.println(" ok");
  }

  Serial.print("   rainbow");
  Serial.flush();
  for (uint16_t h = 0; h < 256; h += 2) {
    uint8_t r, g, b;
    hueToRgb(h, r, g, b);
    led(r, g, b);
    if (!waitMs(12)) { ledOff(); return; }
  }
  Serial.println(" ok");
  ledOff();

  confirm(CHK_LED, "Did you see all four colours and the sweep?");
}

static void testBuzzer() {
  Serial.println("\n-- Buzzer (LS1) ------------------------------------------");
  Serial.println("   Expect: three short beeps, then one long.");

  for (uint8_t i = 0; i < 3; i++) {
    digitalWrite(BUZZER_GPIO, HIGH);
    if (!waitMs(90))  { digitalWrite(BUZZER_GPIO, LOW); return; }
    digitalWrite(BUZZER_GPIO, LOW);
    if (!waitMs(160)) return;
  }
  if (!waitMs(250)) return;
  digitalWrite(BUZZER_GPIO, HIGH);
  if (!waitMs(500)) { digitalWrite(BUZZER_GPIO, LOW); return; }
  digitalWrite(BUZZER_GPIO, LOW);

  confirm(CHK_BUZZER, "Did you hear it?");
}

/* Walk the bank one relay at a time. This is the test that proves the whole
 * silkscreen -> terminal -> relay -> ULN channel -> GPIO mapping, so it
 * prints every one of those and you follow along on the board. */
static void testRelaysIndividually() {
  Serial.println("\n-- Relays, one at a time ---------------------------------");
  Serial.println("   Needs 12 V on J1. Listen for eight clicks in order.");
  Serial.println();
  Serial.println("   Silk  Terminal  Relay  ULN    GPIO");
  Serial.println("   ----  --------  -----  -----  ----");

  for (uint8_t i = 0; i < RELAY_COUNT; i++) {
    Serial.printf("   %-4u  %-8s  %-5s  IN%-3u  %-4u",
                  i + 1, RELAY_TERM[i], RELAY_REF[i], RELAY_ULN_IN[i], RELAY_GPIO[i]);
    Serial.flush();

    relayWrite(i, true);
    if (!waitMs(RELAY_ON_MS)) { relaysAllOff(); return; }
    relayWrite(i, false);
    Serial.println("  click");
    if (!waitMs(RELAY_OFF_MS)) { relaysAllOff(); return; }
  }
  relaysAllOff();

  Serial.println();
  confirm(CHK_RELAY_EACH, "Eight clicks, in silkscreen order 1 to 8?");
}

/* All eight coils at once: 8 x 71.4 mA = 571 mA off the 5 V rail, and about
 * 0.5 W in the ULN2803A. The LMR51430 is rated 3 A, so this is comfortable -
 * it is here to catch a weak rail or a marginal coil, not to stress anything.
 * Two seconds is long enough to see a droop and short enough to stay cool. */
static void testRelaysAllOn() {
  Serial.println("\n-- All relays on together --------------------------------");
  Serial.println("   571 mA on the 5 V rail for 2 s. ULN gets warm; that is normal.");

  for (uint8_t i = 0; i < RELAY_COUNT; i++) {
    relayWrite(i, true);
    delay(25);                      /* stagger slightly to soften inrush */
  }
  Serial.println("   all energised");
  if (!waitMs(2000)) { relaysAllOff(); return; }
  relaysAllOff();
  Serial.println("   all released");

  Serial.println();
  confirm(CHK_RELAY_ALL, "Did all eight hold without the board resetting?");
}

static void testRelayChase() {
  Serial.println("\n-- Relay chase (any key stops) ---------------------------");
  uint8_t i = 0;
  for (;;) {
    relaysAllOff();
    relayWrite(i, true);
    uint8_t r, g, b;
    hueToRgb((uint8_t)(i * 32), r, g, b);
    led(r / 8, g / 8, b / 8);       /* dim, so it is not blinding */
    if (!waitMs(CHASE_MS)) break;
    i = (i + 1) % RELAY_COUNT;
  }
  relaysAllOff();
  ledOff();
}

/* Everything at once: two laps of the relay bank with the status LED tracking
 * the active channel and a beep at the end of each lap. This is the stage that
 * shows the 5 V rail carrying a coil, the buzzer and the WS2812B together
 * rather than one at a time. */
static void testFinale() {
  Serial.println("\n-- All components together -------------------------------");
  Serial.println("   Two laps: each relay in turn, LED follows, beep per lap.");

  for (uint8_t lap = 0; lap < 2; lap++) {
    Serial.printf("   lap %u:", lap + 1);
    Serial.flush();

    for (uint8_t i = 0; i < RELAY_COUNT; i++) {
      relaysAllOff();
      relayWrite(i, true);
      uint8_t r, g, b;
      hueToRgb((uint8_t)(i * 32), r, g, b);
      led(r / 4, g / 4, b / 4);
      Serial.printf(" %u", i + 1);
      Serial.flush();
      if (!waitMs(CHASE_MS)) { allOutputsOff(); return; }
    }

    relaysAllOff();
    ledOff();
    digitalWrite(BUZZER_GPIO, HIGH);
    if (!waitMs(120)) { allOutputsOff(); return; }
    digitalWrite(BUZZER_GPIO, LOW);
    Serial.println(" beep");
    if (!waitMs(350)) { allOutputsOff(); return; }
  }
  allOutputsOff();
}

/* Live edge monitor. The only way to test a dry contact and a button is to
 * have someone press them. */
static void testInputsLive() {
  Serial.println("\n-- Input monitor (any key stops) -------------------------");
  Serial.println("   Short J7 pin 1 to pin 2, and press SW3 / SW2.");

  bool in1 = digitalRead(INPUT1_GPIO);
  bool usr = digitalRead(USER_BTN_GPIO);
  bool bt  = digitalRead(BOOT_BTN_GPIO);
  bool sawIn1 = false, sawUsr = false;

  for (;;) {
    bool n1 = digitalRead(INPUT1_GPIO);
    bool nu = digitalRead(USER_BTN_GPIO);
    bool nb = digitalRead(BOOT_BTN_GPIO);

    if (n1 != in1) {
      Serial.printf("   [%7lu ms] Input 1 (J7)   -> %s\n",
                    millis(), n1 ? "OPEN" : "CLOSED");
      in1 = n1; sawIn1 = true;
      led(0, n1 ? 0 : 40, 0);
    }
    if (nu != usr) {
      Serial.printf("   [%7lu ms] SW3 user btn   -> %s\n",
                    millis(), nu ? "PRESSED" : "released");
      usr = nu; sawUsr = true;
      led(0, 0, nu ? 40 : 0);
    }
    if (nb != bt) {
      Serial.printf("   [%7lu ms] SW2 BOOT btn   -> %s\n",
                    millis(), nb ? "released" : "PRESSED");
      bt = nb;
    }
    if (aborted()) break;
    delay(8);
  }
  ledOff();
  if (sawIn1) mark(CHK_INPUT1,  R_PASS, "toggled under test");
  if (sawUsr) mark(CHK_USERBTN, R_PASS, "pressed under test");
}

/* Half-duplex turn-around. Raise DE, write, wait for the shift register to
 * empty, hold the line a moment, then drop DE - dropping it early truncates
 * the last byte, which is the classic RS-485 bug. Serial2.flush() on the
 * ESP32 blocks until the transmitter is idle, which is what we need here.
 *
 * Disabling the driver then lets A/B relax from driven levels to the much
 * weaker fail-safe bias levels. With JP1 unfitted the stub is unterminated,
 * so that settle is slow, and because DE and /RE are tied together our own
 * receiver switches back on partway through it and reads a few bytes of
 * nonsense. That is the transceiver behaving normally, not a board fault. A
 * real protocol discards it on the CRC; this test counts and bins it, so the
 * echo display below only shows traffic that genuinely came from elsewhere. */
static void testRs485() {
  Serial.println("\n-- RS-485 (J12) ------------------------------------------");
  Serial.println("   Sending 5 frames at 9600 8N1. Watch A/B on a scope, or");
  Serial.println("   hook up a USB-RS485 dongle. Fit JP1 only at a bus end.");

  Serial2.begin(9600, SERIAL_8N1, RS485_RX_GPIO, RS485_TX_GPIO);

  /* DE and /RE are tied together, so enabling the driver also disables the
   * receiver - and a disabled MAX3485 drives RO to high impedance. There is
   * no pull-up on RO in rev 1, so GPIO16 floats for the whole of every
   * transmission and the UART clocks in phantom bytes from the crosstalk.
   * The ESP32's internal pull-up holds it in the idle mark instead. Set it
   * after begin(), which otherwise leaves the pin with no pull. */
  gpio_set_pull_mode((gpio_num_t)RS485_RX_GPIO, GPIO_PULLUP_ONLY);
  delay(20);

  uint16_t binned = 0;
  for (uint8_t i = 0; i < 5; i++) {
    digitalWrite(RS485_DIR_GPIO, HIGH);        /* drive */
    delayMicroseconds(100);                    /* driver enable time */
    Serial2.printf("SELFTEST frame %u\r\n", i + 1);
    Serial2.flush();                           /* transmitter idle */
    delayMicroseconds(1000);                   /* hold the idle mark */
    digitalWrite(RS485_DIR_GPIO, LOW);         /* back to receive */

    delay(3);                                  /* let A/B settle to bias */
    while (Serial2.available()) { Serial2.read(); binned++; }

    Serial.printf("   sent frame %u\n", i + 1);
    if (!waitMs(200)) break;
  }
  if (binned) Serial.printf("   binned %u byte(s) of turn-around noise\n", binned);

  Serial.println("   Listening for 5 s - anything received is echoed below.");
  uint32_t t0 = millis();
  uint16_t rx = 0;
  while (millis() - t0 < 5000) {
    while (Serial2.available()) {
      char c = (char)Serial2.read();
      if (rx == 0) Serial.print("   rx: ");
      Serial.print(c >= 32 && c < 127 ? c : '.');
      rx++;
    }
    if (aborted()) break;
    delay(5);
  }
  if (rx) Serial.printf("\n   %u byte(s) received from the bus\n", rx);
  else    Serial.println("   nothing received (expected with J12 empty)");
}
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
void loop() {
  if (!Serial.available()) { delay(10); return; }

  char c = (char)Serial.read();
  if (c == '\r' || c == '\n' || c == ' ') return;
  Serial.println(c);

  switch (c) {
    case '1': testLed();                break;
    case '2': testBuzzer();             break;
    case '3': testRelaysIndividually(); break;
    case '4': testRelaysAllOn();        break;
    case '5': testRelayChase();         break;
    case '6': testInputsLive();         break;
    case '7': testRs485();              break;
    case '8': checkI2c();               break;
    case '9': testFinale();             break;
    case 'a':
    case 'A': runAll();                 break;
    case 'r':
    case 'R': printReport();            break;
    case '0':
      allOutputsOff();
      Serial.println("   all outputs off");
      break;
    default:
      printMenu();
      return;
  }
  printMenu();
}

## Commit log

2026-10-06 Add hardware self-test firmware, validated on the first built board
    firmware/self-test/ exercises every fitted component and prints a
    pass/fail report over USB serial. No libraries beyond the Arduino-ESP32
    core - the WS2812B uses the core's built-in neopixelWrite().
    Passive checks run at boot (rails, USB/CH340C path, RS-485 receiver
    idle, input pull resistors, I2C bus). Everything that moves, sounds or
    lights up is on a menu or in a continuous full sweep, since only an
    operator can confirm a relay actually clicked. The relay walk prints
    silkscreen number, terminal, designator, ULN channel and GPIO for each
    channel, which is what validates that mapping end to end.
    Brought up on the first as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
    [self-test.ino]
2026-10-06 Correct the upload-rate finding: 921600 is unreachable, not unreliable
    The previous commit claimed 921600 fails because the CH340C and the USB-C
    stub "do not carry it reliably", and set 460800 as a safe fallback. Both
    the reason and the fallback were wrong.
    Sweeping the rate shows the failures are not above a threshold but at
    particular rates: 460800 ok, 576000 fails, 750000 ok, 921600 fails,
    1000000 ok, 1200000 ok, 1500000 ok. 1500000 is 1.6x faster than the rate
    that fails, so this is not a signal-integrity ceiling.
    The working set is exactly 6_000_000/n, which is what the CH340C's clock
    divider gives if the host driver uses only the coarse prescaler. 921600
    is not expressible; the drive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
2026-10-06 Run the self-test on boot instead of waiting for a serial command
    Flashing the sketch and watching the board produced nothing at all: the
    tests were menu-driven, so with no terminal attached it printed a banner
    nobody could see and then sat in loop() waiting for a keystroke. Needing
    to know a command is a poor way to greet a freshly built board.
    Now, on boot it flashes the LED through three colours and beeps once -
    visible proof of life for someone looking at the board rather than a
    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
